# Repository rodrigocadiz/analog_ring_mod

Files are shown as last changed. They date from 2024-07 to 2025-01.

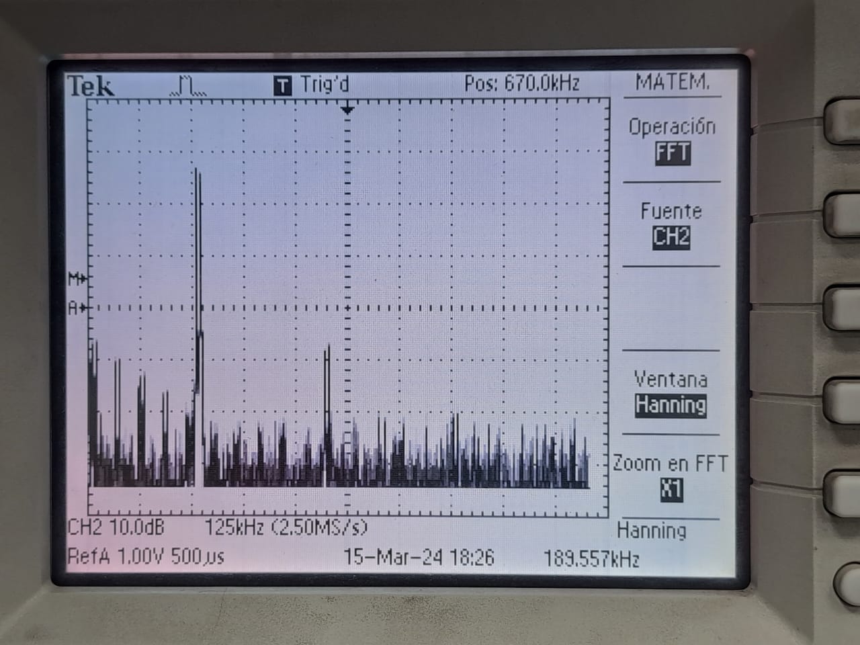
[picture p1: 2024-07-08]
LTSpice paper simulations/Simulaciones paper/Imágenes simulaciones reales/AD633.jpeg

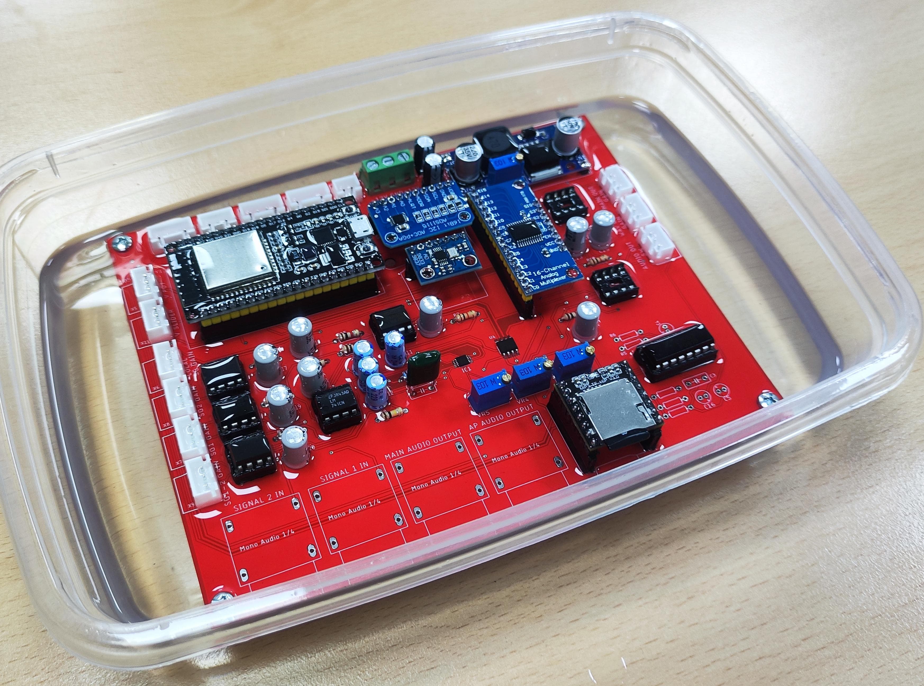
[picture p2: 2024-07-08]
LTSpice paper simulations/Simulaciones paper/Imágenes simulaciones reales/PCB.jpeg

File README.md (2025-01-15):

# Analog ring modulation: a DIY approach inspired by historical techniques

## Overview

We present a device that implements a ring modulator intended to recreate historical analog audio. As simple as it sounds, the multiplication of two analog audio signals is not a straightforward task, mainly due to phenomena such as saturation or non-linearity. Drawing inspiration from historical realizations of ring modulation, we experimented with the most common methods described in the literature. Our device, which is comparatively inexpensive, improves upon the aforementioned alternatives from a DIY perspective. It is predominantly analog, adhering to the practices of the first decades of electroacoustic music, with the notable exception of the digital control for the sinusoidal carrier. We aim to strike a balance between analog audio technology and modern components and techniques. Additionally, this paper includes audio-visual demonstrations that showcase the practical uses of our ring modulator. A comprehensive GitHub repository provides open access to all the resources required for DIY enthusiasts to replicate our implementation.

## Authors
Tomas Koljatic, Michel Rozas, Cristián Garcés, Juan Parra Cancino, Rodrigo F. Cádiz

Pontificia Universidad Católica de Chile

Orpheus Instituut

## Demo videos 
Video 1:
IMAGE ALT TEXT (http://www.youtube.com/watch?v=Msjlwba8t8I "Analog ring modulation: a DIY approach inspired by historical techniques: Video 1")

Video 2: 
IMAGE ALT TEXT (http://www.youtube.com/watch?v=kj30MS5Sc_M "Analog ring modulation: a DIY approach inspired by historical techniques: Video 2")

## Software Installation

The software for the Ring Modulator project is developed to be used with PlatformIO, an open source ecosystem for IoT development. To get started with PlatformIO, you can follow the installation guide here:

- [PlatformIO Installation Guide](https://docs.platformio.org/en/latest/core/installation.html)

Once PlatformIO is installed, you can clone this repository and open the firmware folder project within PlatformIO IDE.

## Hardware Design

The hardware for the Ring Modulator is developed using Autodesk Eagle. This provides a robust framework for designing printed circuit boards (PCBs) that are crucial for our project. You can find the hardware design files in the `hardware` directory of this repository.

For those new to Autodesk Eagle, you can learn more and get started with your designs here:

- [Autodesk Eagle](https://www.autodesk.com/products/eagle/overview)

## Acknowledgments/Contributing

The authors would like to thank Stockahusen Stiftung fur Musik for their support; María Julia Mancero for her participation as a piano performer in the videos; and the anonymous reviewers for their insightful comments and suggestions. This project was funded by the Office for the Arts and Culture of the Vice Presidency for Research, Pontificia Universidad Católica de Chile (ArTeCiH grant) and by ANID/Fondecyt 1230926 and ANID/Anillo ATE220041.

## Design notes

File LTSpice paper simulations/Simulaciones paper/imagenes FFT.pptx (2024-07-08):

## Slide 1

Time and frequency domain response for diode and opamps based modulator

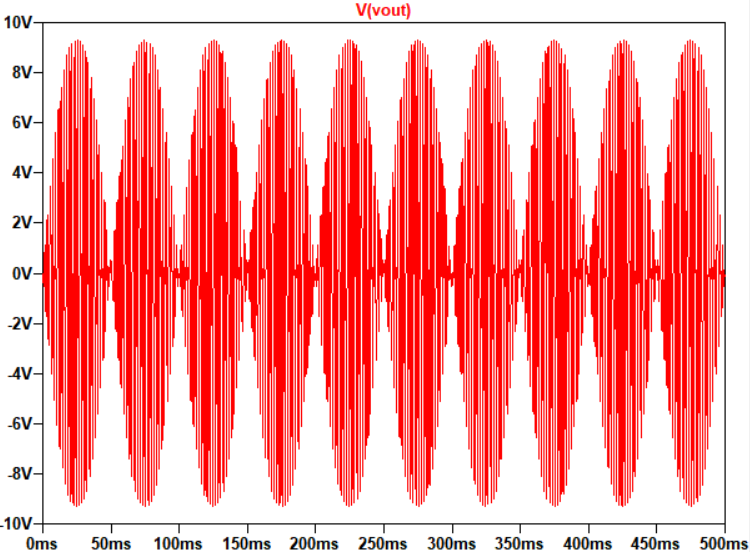
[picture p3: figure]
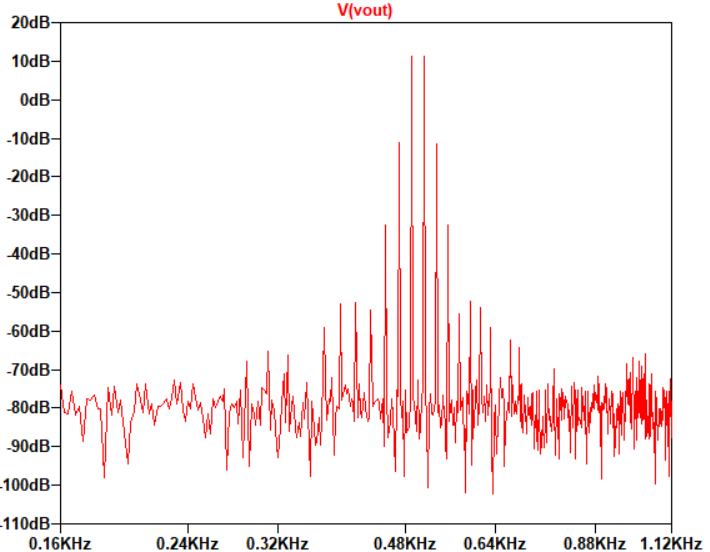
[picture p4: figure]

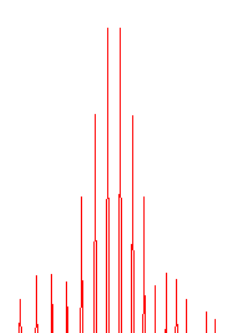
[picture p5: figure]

useful frequencies

20dB

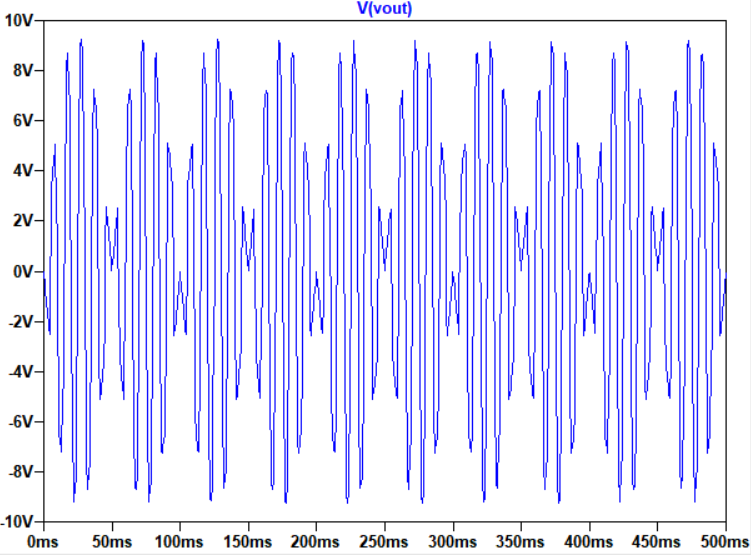
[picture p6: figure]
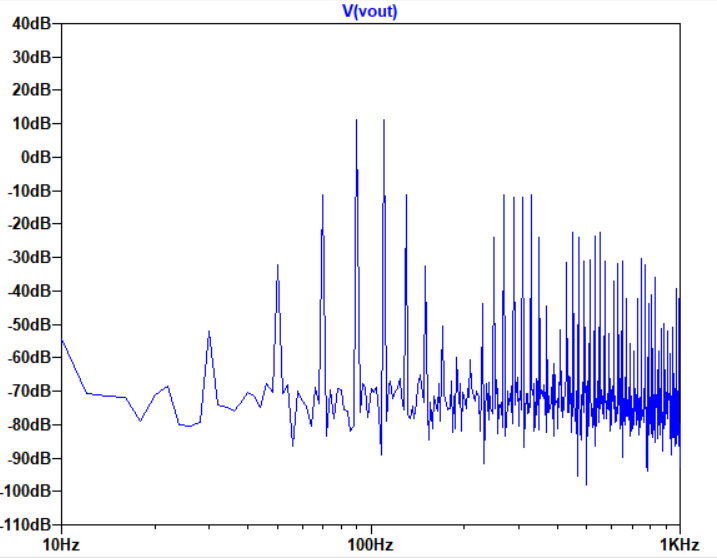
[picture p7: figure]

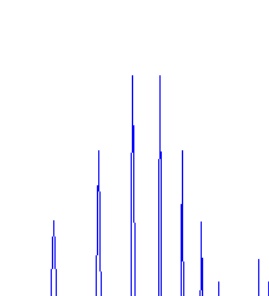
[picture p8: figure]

useful frequencies

20dB

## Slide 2

Time and frequency domain response for MOSFET and opamps based modulator

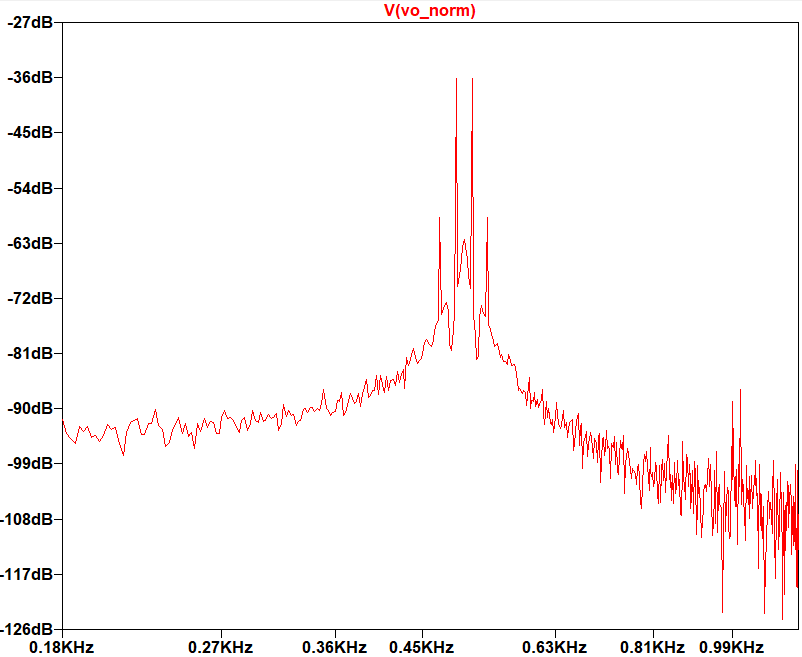
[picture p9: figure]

useful frequencies

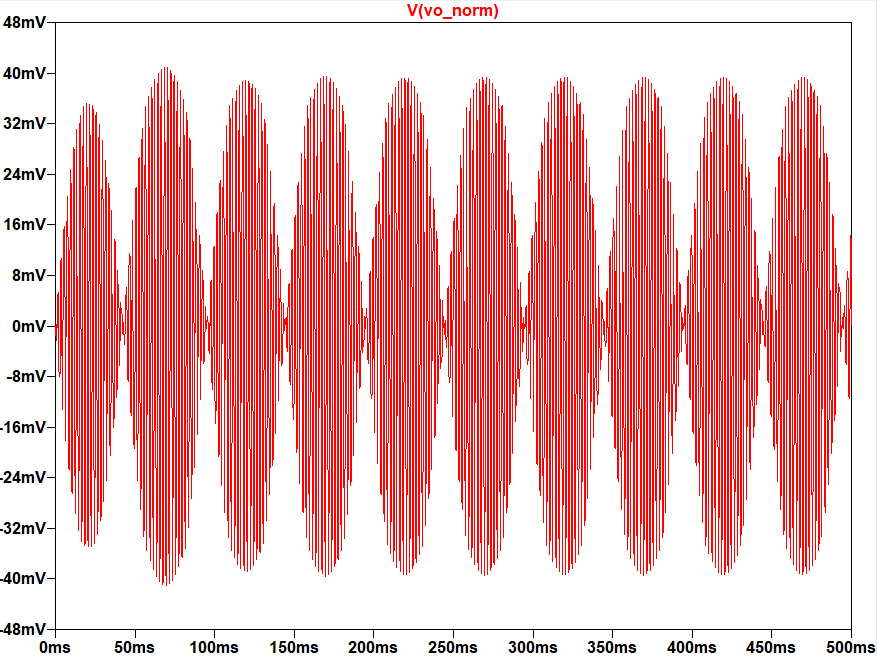
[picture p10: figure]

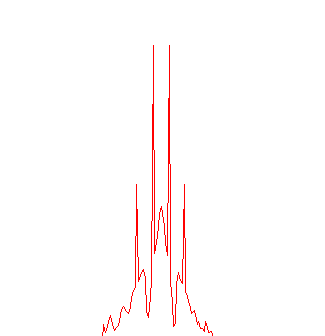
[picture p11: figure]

36 dB

useful frequencies

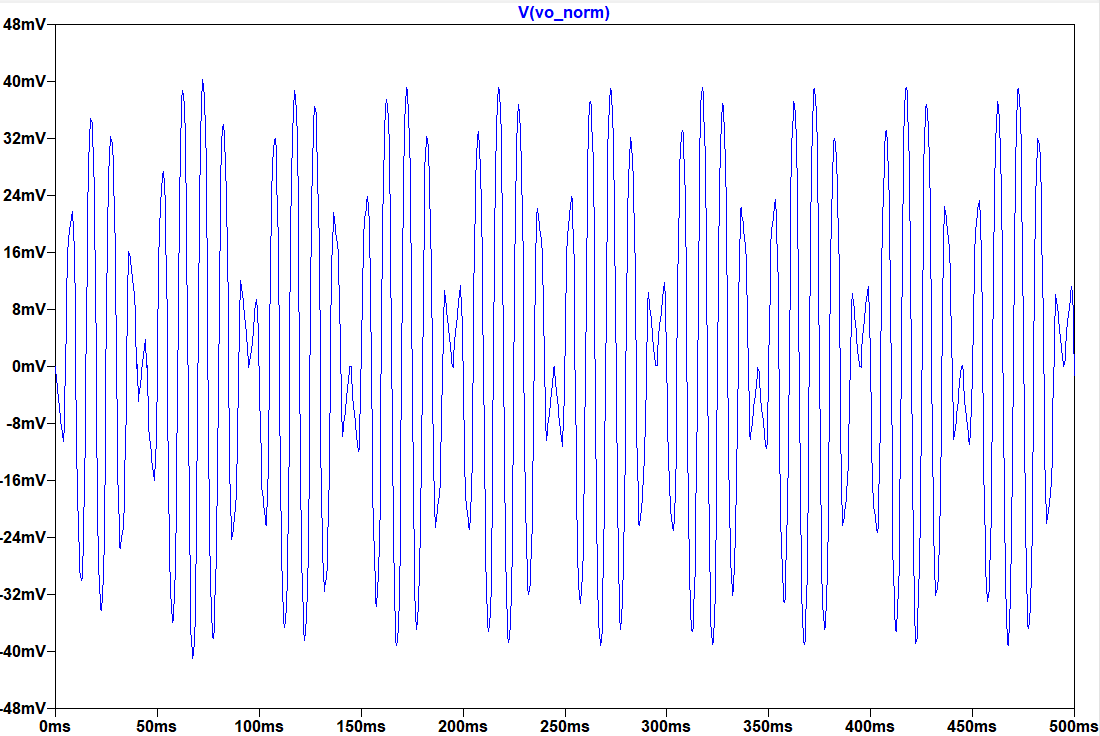
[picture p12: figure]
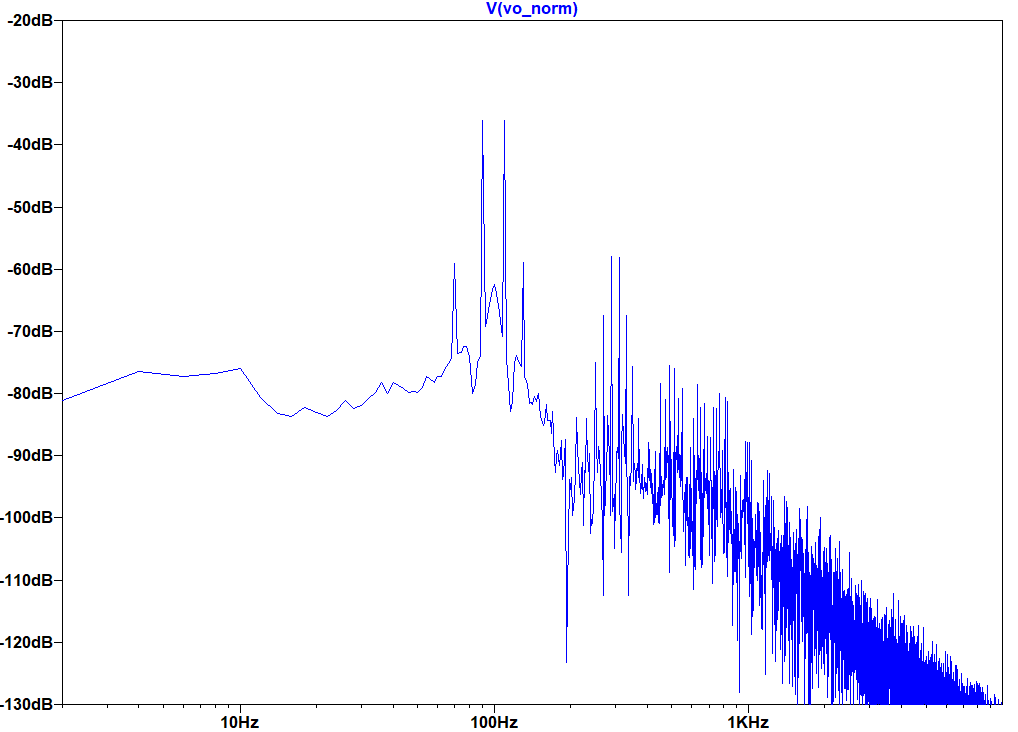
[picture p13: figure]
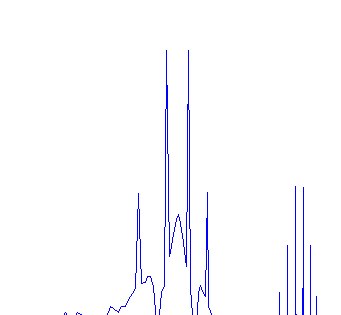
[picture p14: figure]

40dB

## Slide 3

Time and frequency domain response for AD633 IC based modulator

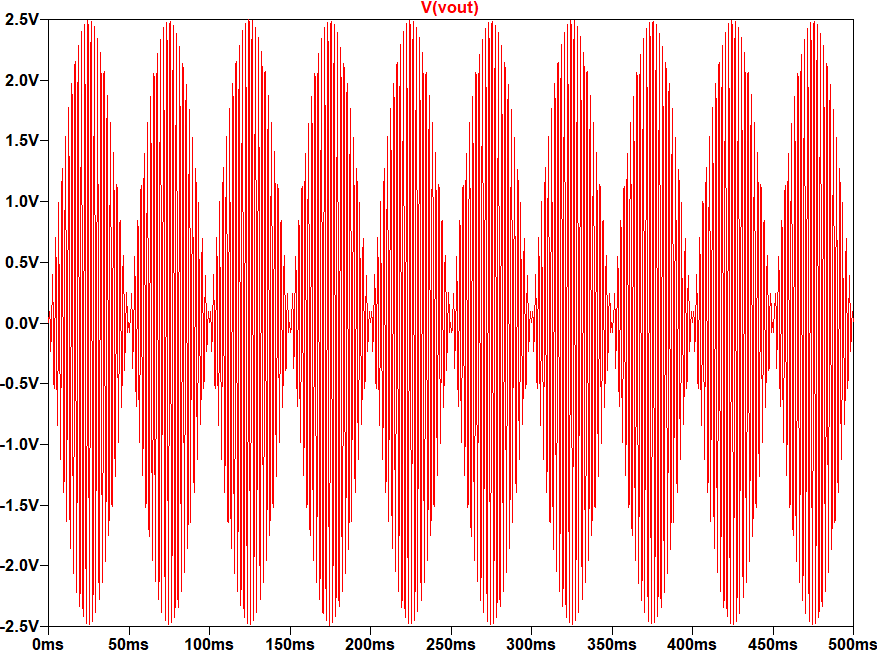
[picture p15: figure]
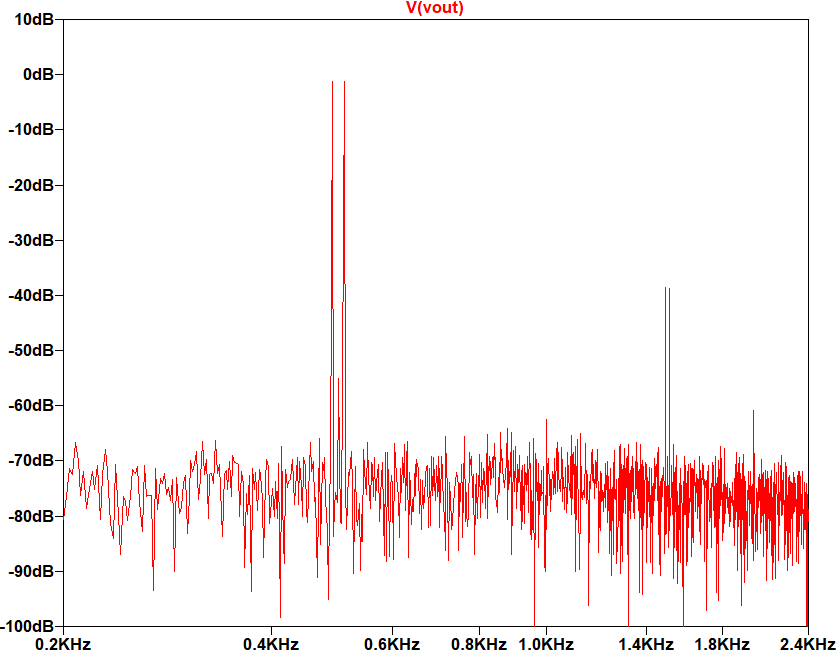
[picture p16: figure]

useful frequencies

40 dB

useful frequencies

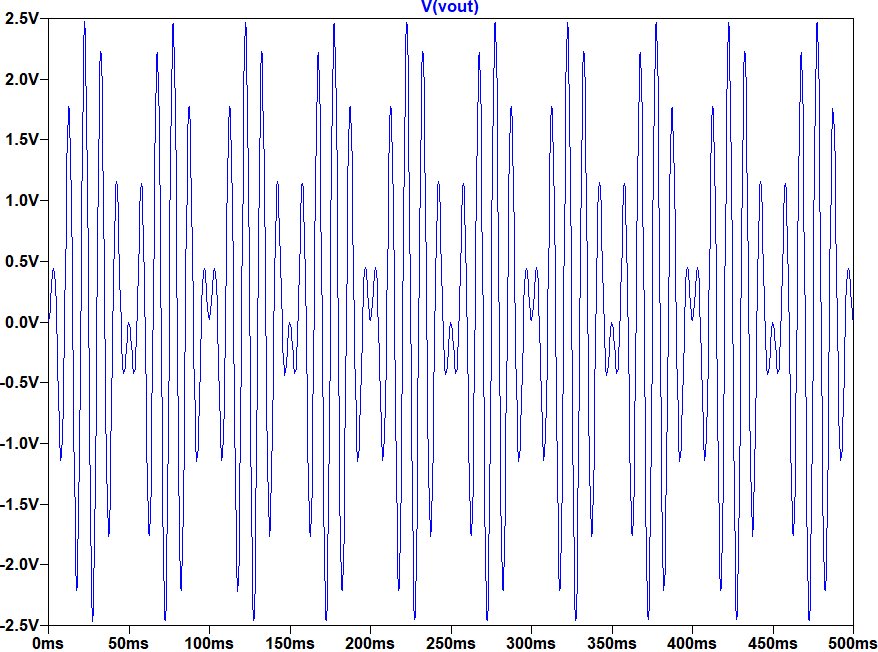
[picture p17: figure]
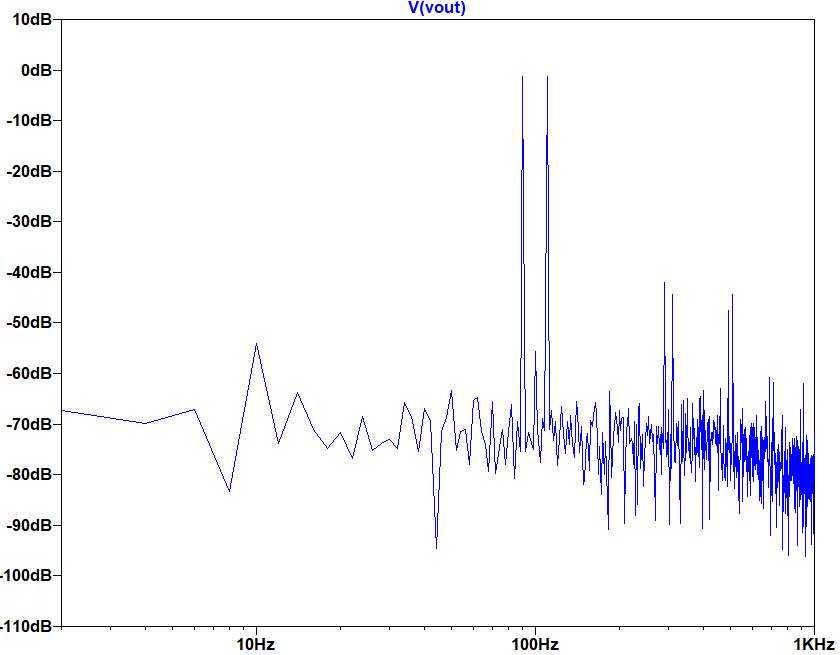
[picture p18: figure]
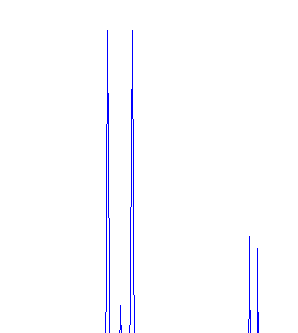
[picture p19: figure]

50dB

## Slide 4

Time and frequency domain response for transformer and diodes based modulator

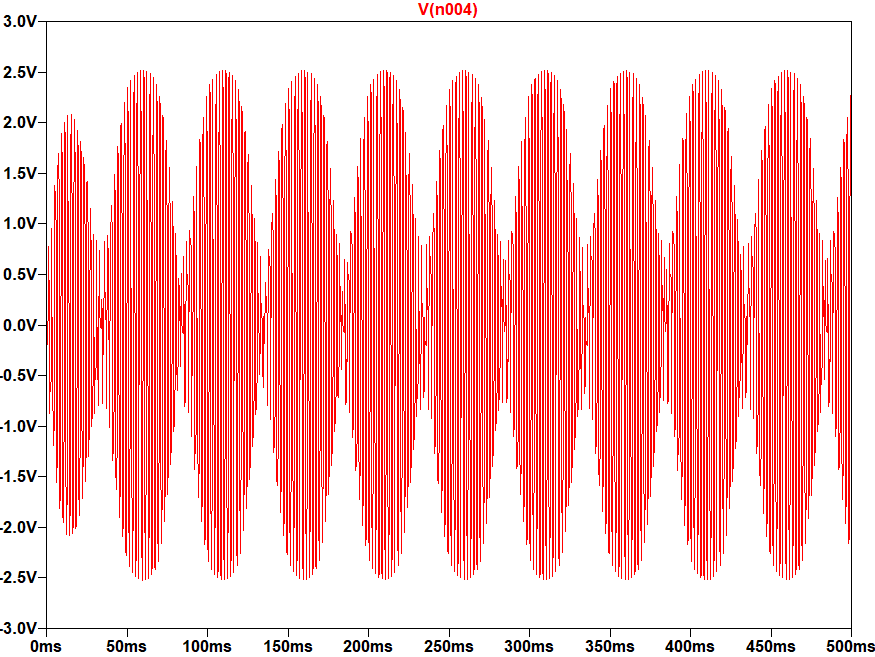
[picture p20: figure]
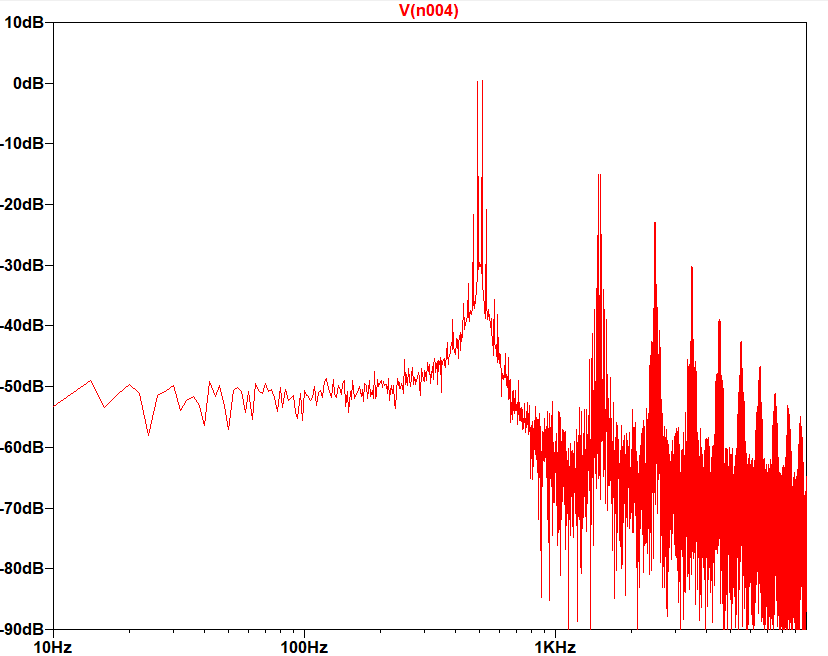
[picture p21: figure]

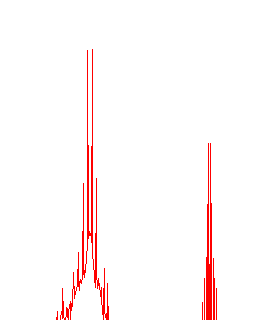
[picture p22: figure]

useful frequencies

20dB

useful frequencies

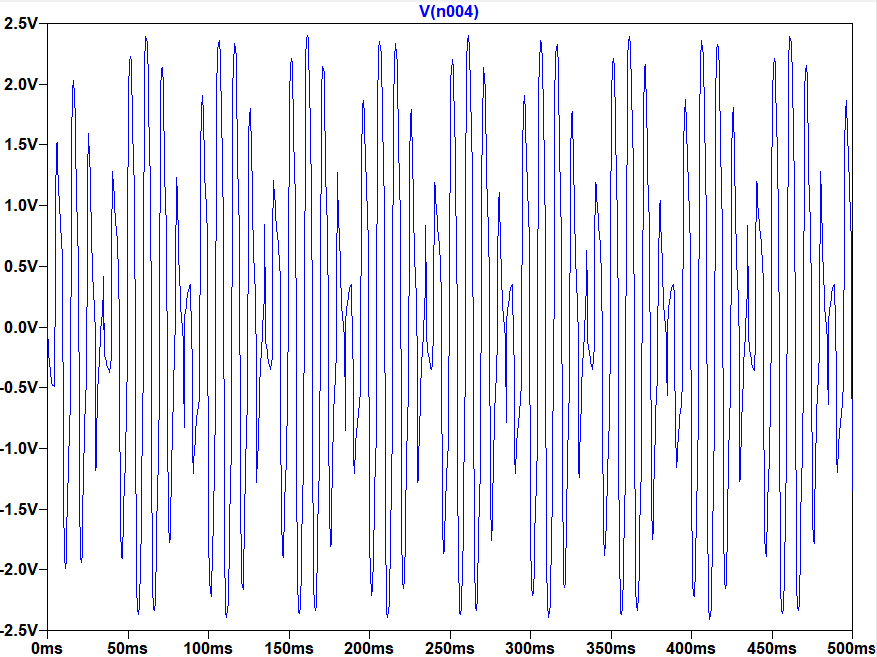
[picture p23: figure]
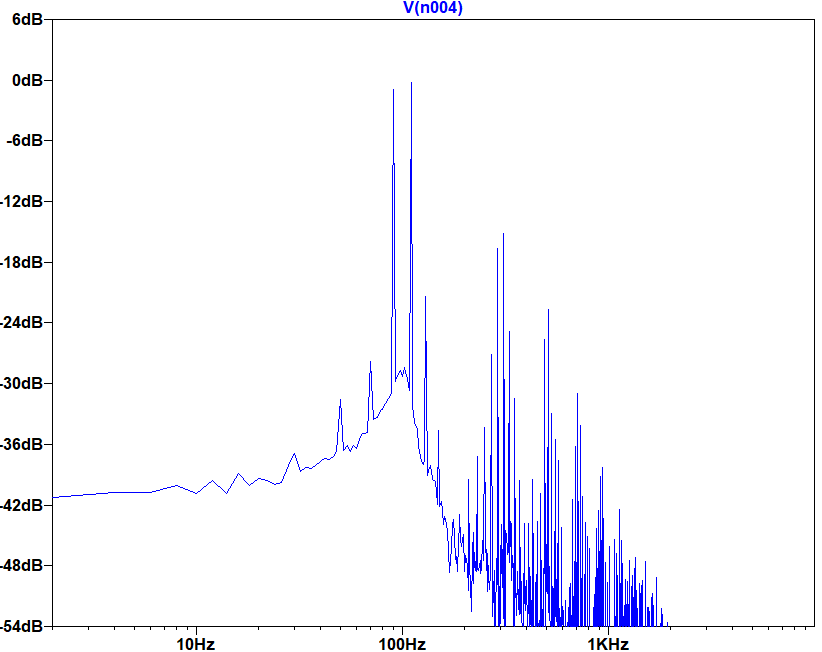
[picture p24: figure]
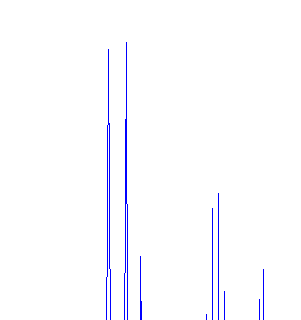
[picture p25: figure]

15 dB

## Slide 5

Time and frequency domain response for transformer and diodes based modulator

useful frequencies

20dB

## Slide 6

Time and frequency domain response for diode and op-amps based modulator

useful frequencies

20dB

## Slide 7

Time and frequency domain response for MOSFET and op-amps based modulator

useful frequencies

36 dB

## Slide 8

Time and frequency domain response for AD633 IC based modulator

useful frequencies

40 dB

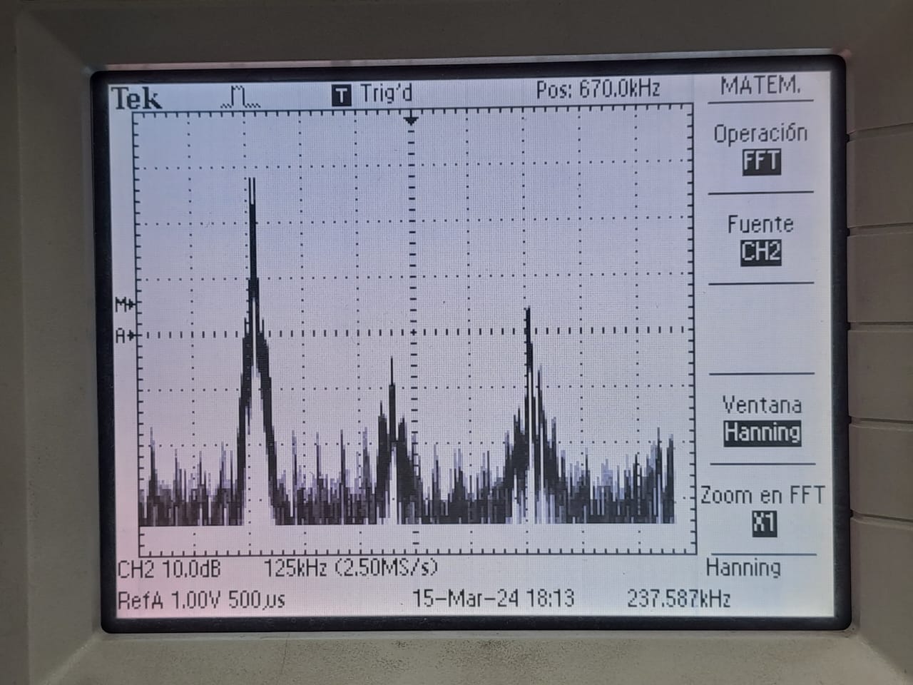
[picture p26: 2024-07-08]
LTSpice paper simulations/Simulaciones paper/Imágenes simulaciones reales/Diodos y opamps.jpeg

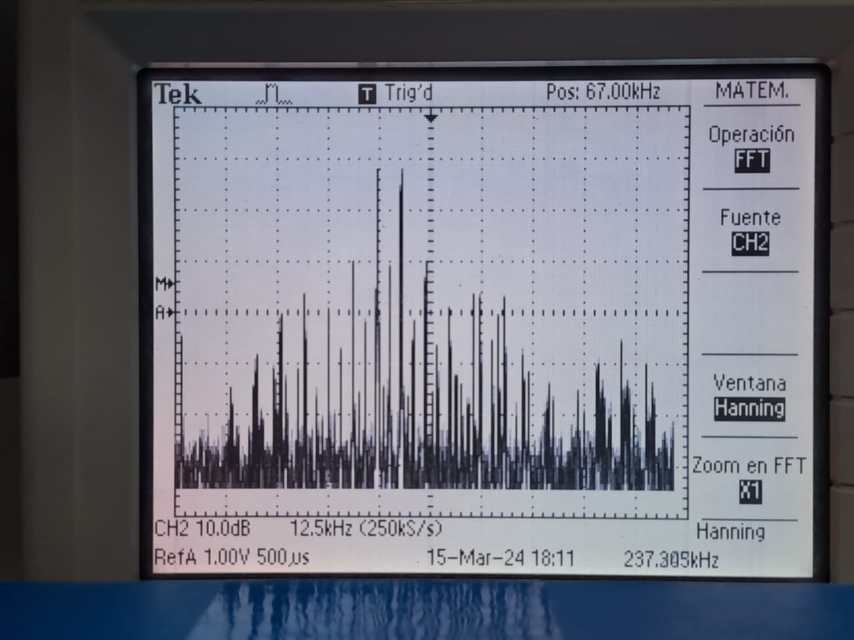
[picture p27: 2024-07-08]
LTSpice paper simulations/Simulaciones paper/Imágenes simulaciones reales/Diodos y opamps (zoom).jpeg

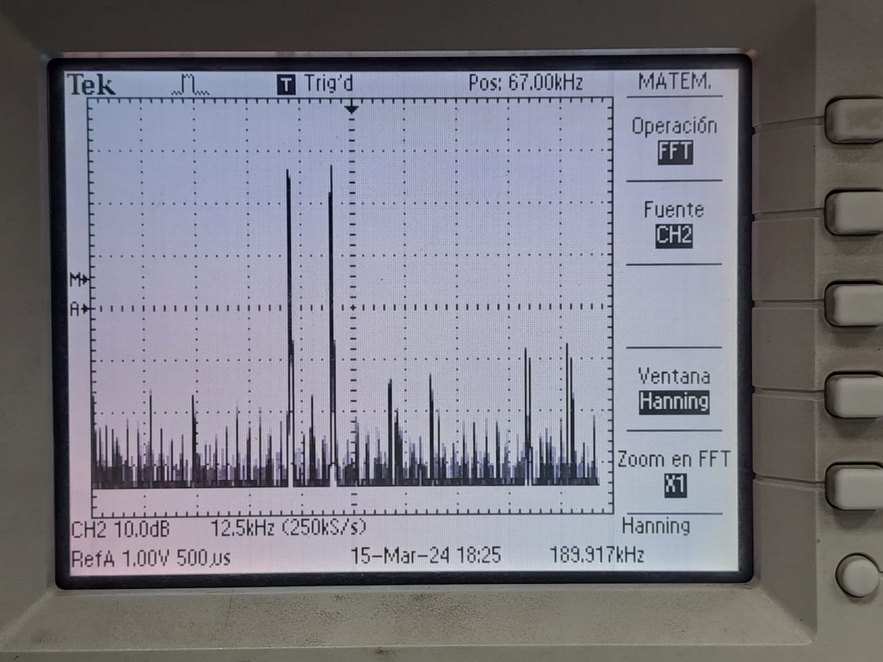
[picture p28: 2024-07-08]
LTSpice paper simulations/Simulaciones paper/Imágenes simulaciones reales/AD633 (zoom).jpeg

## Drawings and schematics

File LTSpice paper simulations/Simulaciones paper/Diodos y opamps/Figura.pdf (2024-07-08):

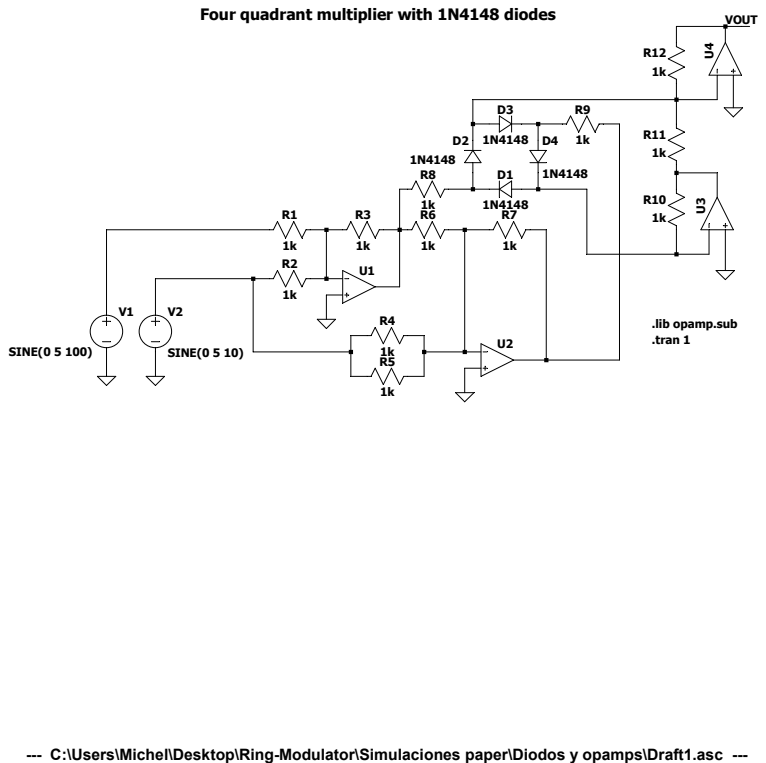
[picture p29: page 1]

Four quadrant multiplier with 1N4148 diodes

--- C:\Users\Michel\Desktop\Ring-Modulator\Simulaciones paper\Diodos y opamps\Draft1.asc ---

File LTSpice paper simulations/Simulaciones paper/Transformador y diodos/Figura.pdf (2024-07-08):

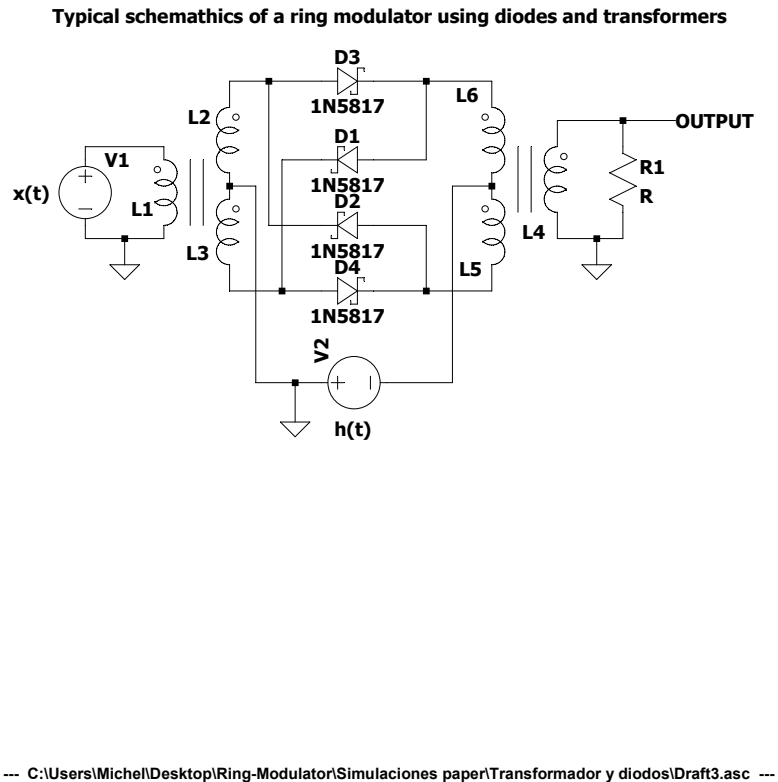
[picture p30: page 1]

Typical schemathics of a ring modulator using diodes and transformers

--- C:\Users\Michel\Desktop\Ring-Modulator\Simulaciones paper\Transformador y diodos\Draft3.asc ---

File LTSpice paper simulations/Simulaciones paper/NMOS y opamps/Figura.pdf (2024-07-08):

## Four quadrant multiplier using NMOS and opamps

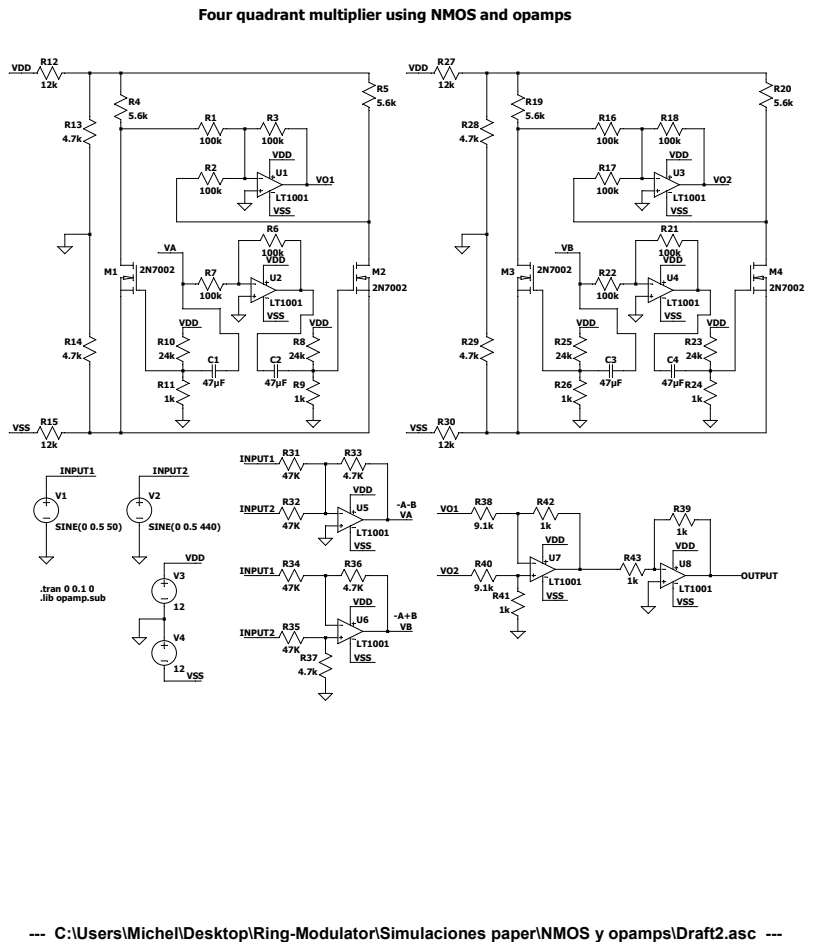
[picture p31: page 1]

--- C:\Users\Michel\Desktop\Ring-Modulator\Simulaciones paper\NMOS y opamps\Draft2.asc ---

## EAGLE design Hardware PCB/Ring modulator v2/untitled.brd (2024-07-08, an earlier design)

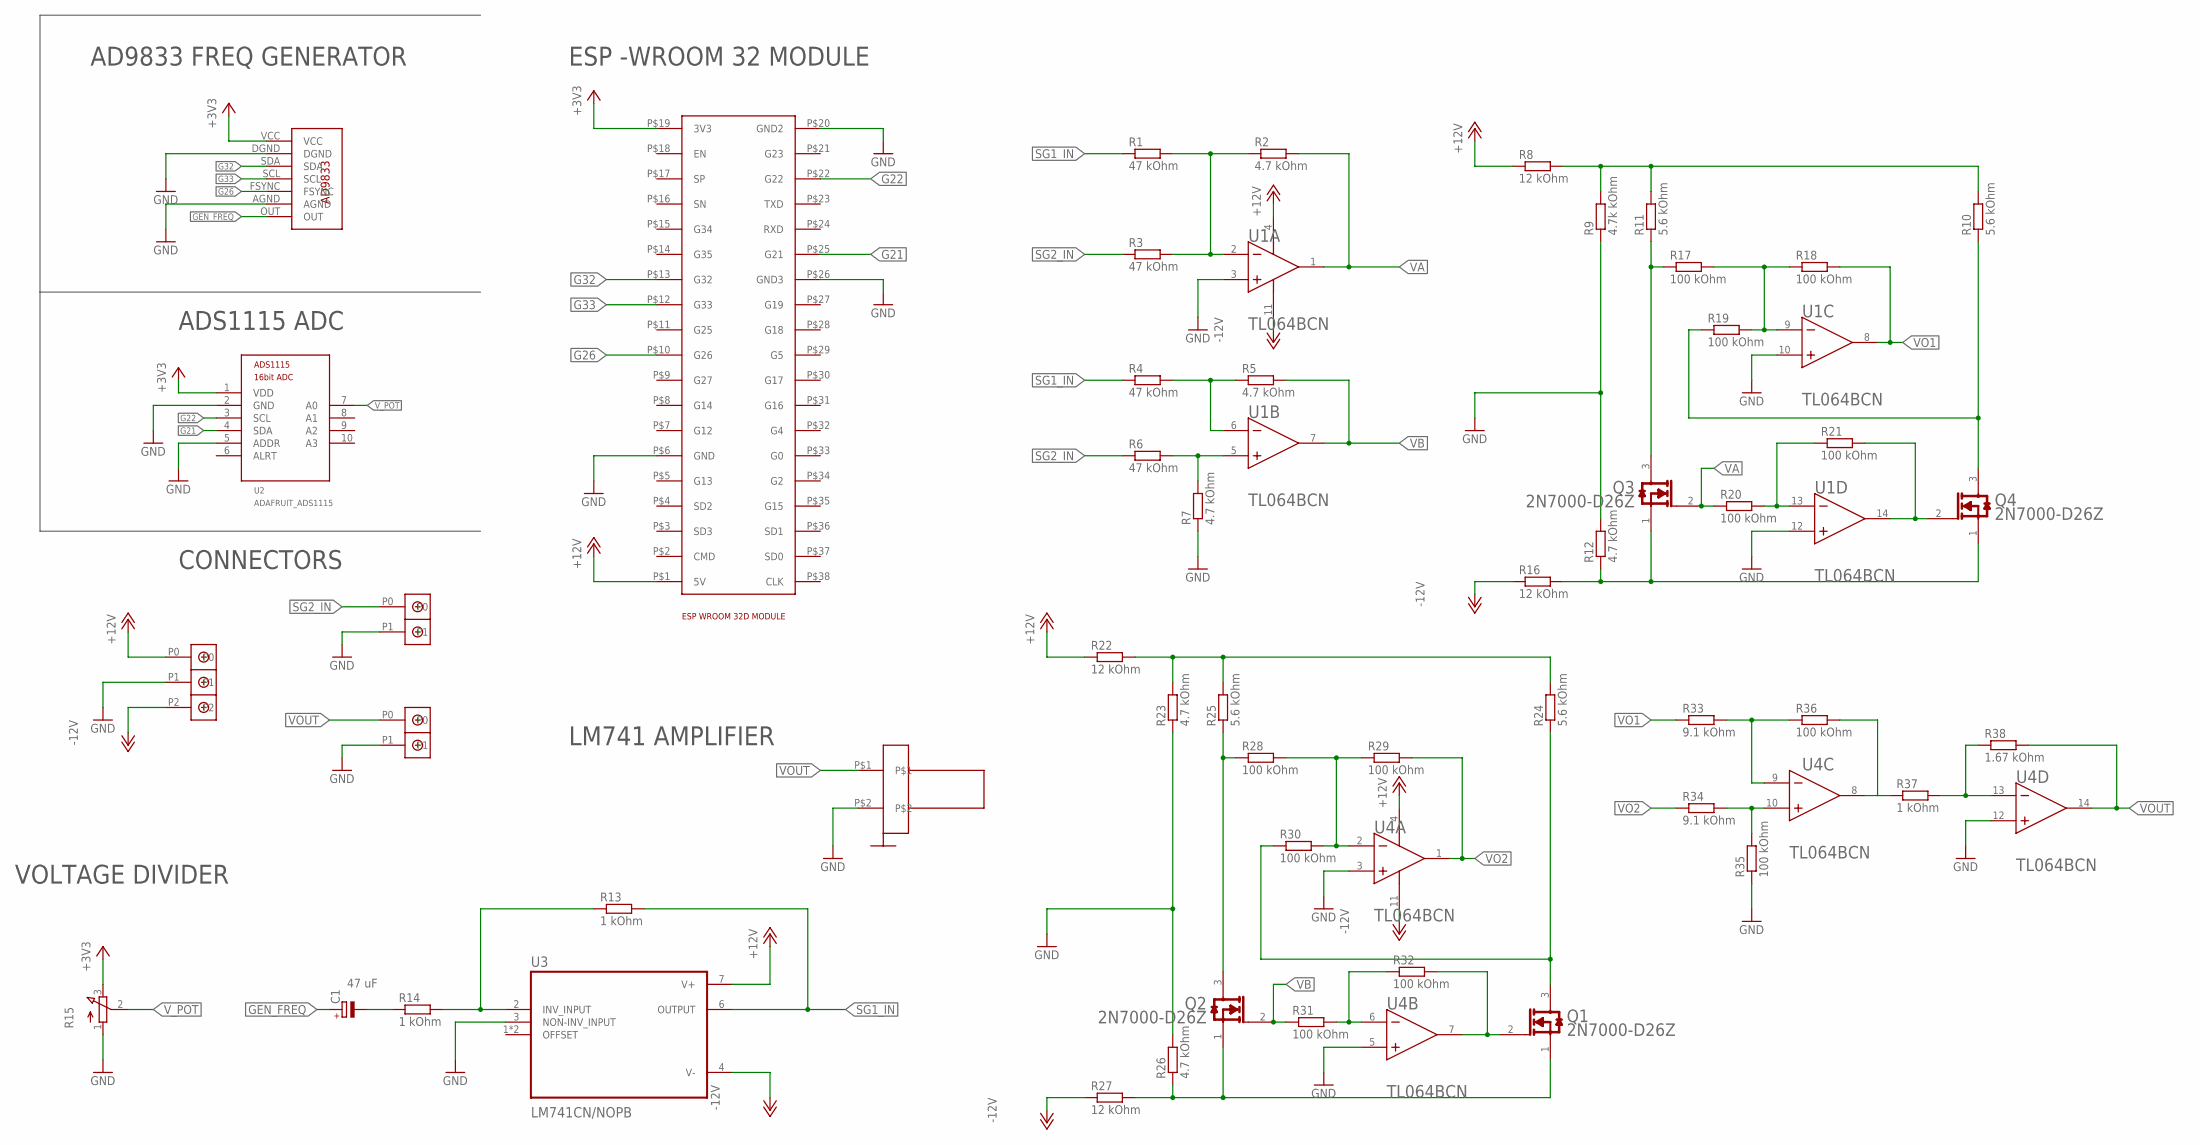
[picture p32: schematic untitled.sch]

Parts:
C1: 47 uF; E1,8-4
Q1, Q2, Q3, Q4: ON_SEMICONDUCTOR_2N7000-D26ZON_SEMICONDUCTOR_2N70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; ON_SEMICONDUCTOR_2N7000-D26Z_0
R1, R3, R4, R6: 47 kOhm; 0204/7
R2, R5, R7, R12, R23, R26: 4.7 kOhm; 0204/7
R8, R16, R22, R27: 12 kOhm; 0204/7
R9: 4.7k kOhm; 0204/7
R10, R11, R24, R25: 5.6 kOhm; 0204/7
R13, R14, R37: 1 kOhm; 0204/7
R15: 3RP/1610N
R17, R18, R19, R20, R21, R28, R29, R30, R31, R32, R35, R36: 100 kOhm; 0204/7
R33, R34: 9.1 kOhm; 0204/7
R38: 1.67 kOhm; 0204/7
U1, U4: TEXAS_INSTRUMENTS_TL064BCNTEXAS_INSTRUMENTS_TL064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; TEXAS_INSTRUMENTS_TL064BCN_0
U2: ADAFRUIT_ADS1115; ADAFRUIT_ADS1115_16BIT_I2C_ADC
U3: LM741CN/NOPB; DIP794W45P254L959H508Q8
U$1: ESP32
U$2: A9833; AD9833
U$3, U$5: DBCONN-1X2
U$4: DBCONN-1X3
U$6: FP

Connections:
+3V3: R15.3 (E), U2.1 (VDD), U$1.P$19 (3V3), U$2.VCC
+12V: R8.1, R22.1, U1.4 (VCC+), U3.7 (V+), U4.4 (VCC+), U$1.P$1 (5V), U$4.P0
-12V: R16.1, R27.1, U1.11 (VCC-), U3.4 (V-), U4.11 (VCC-), U$4.P2
G21: U2.4 (SDA), U$1.P$25 (G21)
G22: U2.3 (SCL), U$1.P$22 (G22)
G26: U$1.P$10 (G26), U$2.FSYNC
G32: U$1.P$13 (G32), U$2.SDA
G33: U$1.P$12 (G33), U$2.SCL
GEN_FREQ: C1.+, U$2.OUT
GND: R7.1, R9.1, R12.2, R15.1 (A), R23.1, R26.2, R35.1, U1.3 (IN1+), U1.10 (IN3+), U1.12 (IN4+), U2.2 (GND), U2.5 (ADDR), U3.3 (NON-INV_INPUT), U4.3 (IN1+), U4.5 (IN2+), U4.12 (IN4+), U$1.P$6 (GND), U$1.P$20 (GND2), U$1.P$26 (GND3), U$2.AGND, U$2.DGND, U$3.P1, U$4.P1, U$5.P1, U$6.P$2
unnamed: R1.2, R2.1, R3.2, U1.2 (IN1-)
unnamed: R4.2, R5.1, U1.6 (IN2-)
unnamed: R8.2, R9.2, R10.2, R11.2
unnamed: R13.1, R14.2, U3.2 (INV_INPUT)
unnamed: C1.-, R14.1
unnamed: R6.2, R7.2, U1.5 (IN2+)
unnamed: Q3.3 (D), R11.1, R17.1
unnamed: Q3.1 (S), Q4.1 (S), R12.1, R16.2
unnamed: Q4.3 (D), R10.1, R19.1
unnamed: R37.2, R38.1, U4.13 (IN4-)
unnamed: R20.2, R21.1, U1.13 (IN4-)
unnamed: R17.2, R18.1, R19.2, U1.9 (IN3-)
unnamed: Q4.2 (G), R21.2, U1.14 (OUT4)
unnamed: R22.2, R23.2, R24.2, R25.2
unnamed: Q1.1 (S), Q2.1 (S), R26.1, R27.2
unnamed: Q2.3 (D), R25.1, R28.1
unnamed: Q1.3 (D), R24.1, R30.1
unnamed: R28.2, R29.1, R30.2, U4.2 (IN1-)
unnamed: R33.2, R36.1, U4.9 (IN3-)
unnamed: R31.2, R32.1, U4.6 (IN2-)
unnamed: Q1.2 (G), R32.2, U4.7 (OUT2)
unnamed: R36.2, R37.1, U4.8 (OUT3)
unnamed: R34.2, R35.2, U4.10 (IN3+)
SG1_IN: R1.1, R4.1, R13.2, U3.6 (OUTPUT)
SG2_IN: R3.1, R6.1, U$3.P0
VA: Q3.2 (G), R2.2, R20.1, U1.1 (OUT1)
VB: Q2.2 (G), R5.2, R31.1, U1.7 (OUT2)
VO1: R18.2, R33.1, U1.8 (OUT3)
VO2: R29.2, R34.1, U4.1 (OUT1)
VOUT: R38.2, U4.14 (OUT4), U$5.P0, U$6.P$1
V_POT: R15.2 (S), U2.7 (A0)

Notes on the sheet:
ESP -WROOM 32 MODULE
AD9833 FREQ GENERATOR
ADS1115 ADC
CONNECTORS
LM741 AMPLIFIER
VOLTAGE DIVIDER

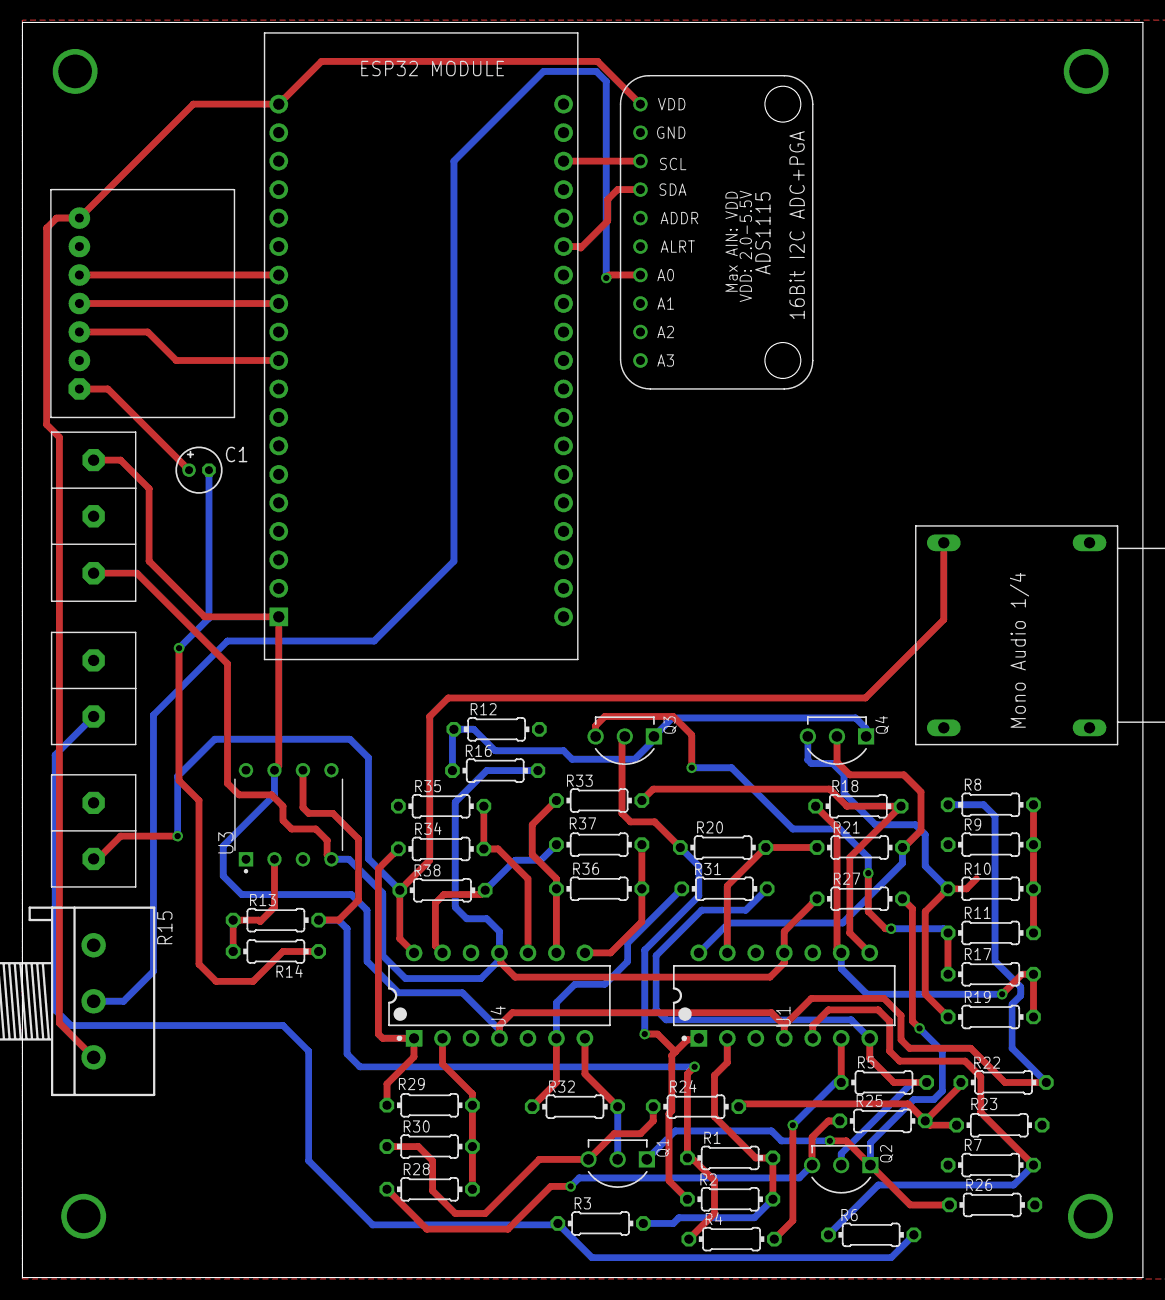
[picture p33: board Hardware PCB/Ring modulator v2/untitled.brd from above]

Board: 2 copper layers, 99.9 x 111.9 mm, 53 parts (0 on the bottom side), 41 nets.

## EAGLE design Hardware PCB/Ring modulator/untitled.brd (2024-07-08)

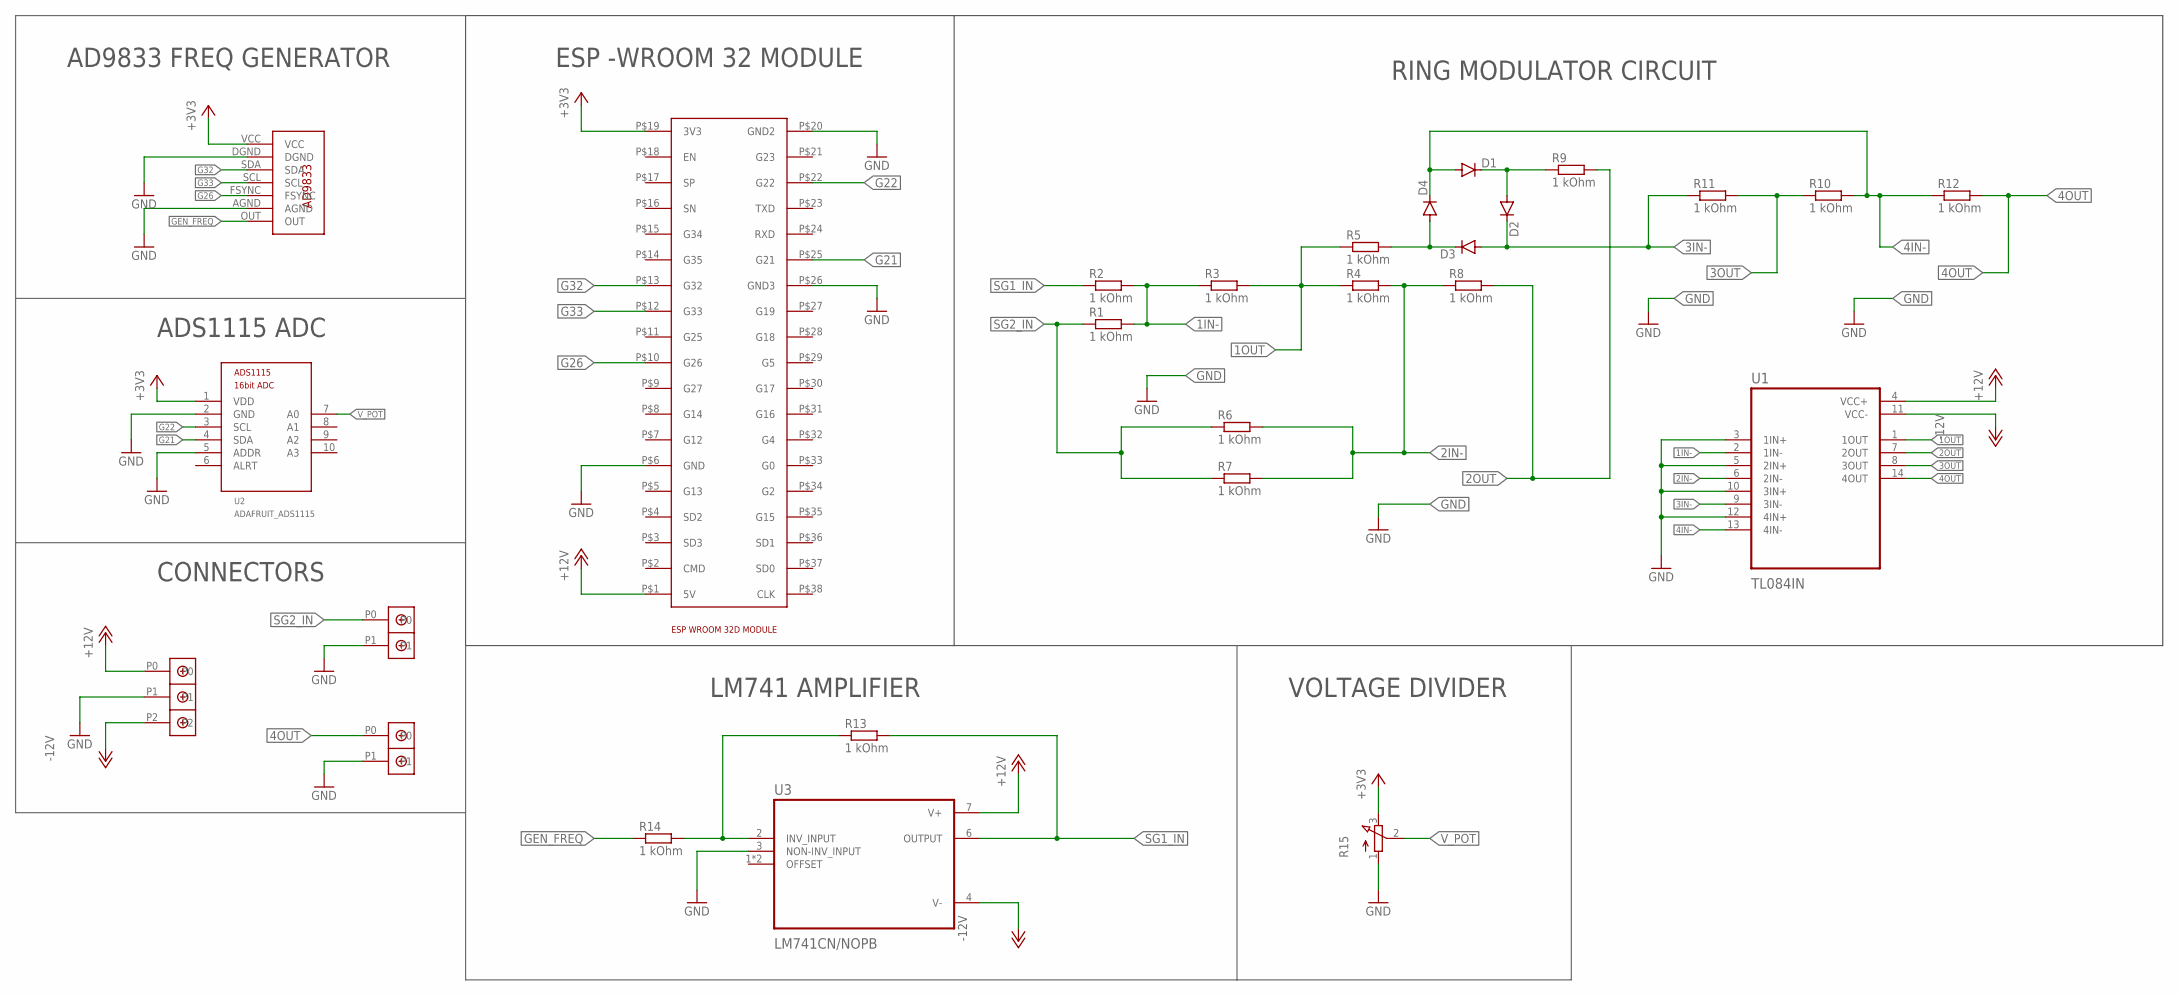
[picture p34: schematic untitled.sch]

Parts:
D1, D2, D3, D4: 1N4148DO35-7; DO35-7
R1, R2, R3, R4, R5, R6, R7, R8, R9, R10, R11, R12, R13, R14: 1 kOhm; 0204/7
R15: 3RP/1610N
U1: TL084IN; DIP794W45P254L1969H508Q14
U2: ADAFRUIT_ADS1115; ADAFRUIT_ADS1115_16BIT_I2C_ADC
U3: LM741CN/NOPB; DIP794W45P254L959H508Q8
U$1: ESP32
U$2: A9833; AD9833
U$3, U$5: DBCONN-1X2
U$4: DBCONN-1X3

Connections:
1IN-: R1.2, R2.2, R3.1, U1.2 (1IN-)
1OUT: R3.2, R4.1, R5.1, U1.1 (1OUT)
2IN-: R4.2, R6.2, R7.2, R8.1, U1.6 (2IN-)
2OUT: R8.2, R9.2, U1.7 (2OUT)
3IN-: D2.C, D3.A, R11.1, U1.9 (3IN-)
3OUT: R10.1, R11.2, U1.8 (3OUT)
4IN-: D1.A, D4.C, R10.2, R12.1, U1.13 (4IN-)
4OUT: R12.2, U1.14 (4OUT), U$5.P0
+3V3: R15.3 (E), U2.1 (VDD), U$1.P$19 (3V3), U$2.VCC
+12V: U1.4 (VCC+), U3.7 (V+), U$1.P$1 (5V), U$4.P0
-12V: U1.11 (VCC-), U3.4 (V-), U$4.P2
G21: U2.4 (SDA), U$1.P$25 (G21)
G22: U2.3 (SCL), U$1.P$22 (G22)
G26: U$1.P$10 (G26), U$2.FSYNC
G32: U$1.P$13 (G32), U$2.SDA
G33: U$1.P$12 (G33), U$2.SCL
GEN_FREQ: R14.1, U$2.OUT
GND: R15.1 (A), U1.3 (1IN+), U1.5 (2IN+), U1.10 (3IN+), U1.12 (4IN+), U2.2 (GND), U2.5 (ADDR), U3.3 (NON-INV_INPUT), U$1.P$6 (GND), U$1.P$20 (GND2), U$1.P$26 (GND3), U$2.AGND, U$2.DGND, U$3.P1, U$4.P1, U$5.P1
unnamed: D3.C, D4.A, R5.2
unnamed: D1.C, D2.A, R9.1
unnamed: R13.1, R14.2, U3.2 (INV_INPUT)
SG1_IN: R2.1, R13.2, U3.6 (OUTPUT)
SG2_IN: R1.1, R6.1, R7.1, U$3.P0
V_POT: R15.2 (S), U2.7 (A0)

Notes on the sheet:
RING MODULATOR CIRCUIT
ESP -WROOM 32 MODULE
AD9833 FREQ GENERATOR
ADS1115 ADC
CONNECTORS
LM741 AMPLIFIER
VOLTAGE DIVIDER

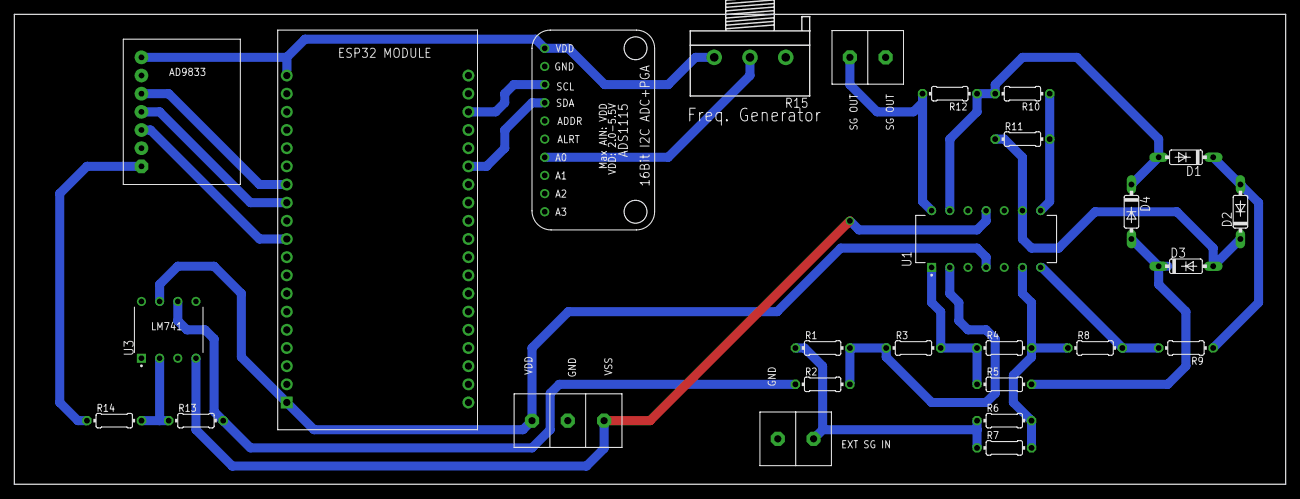
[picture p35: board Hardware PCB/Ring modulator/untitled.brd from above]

Board: 2 copper layers, 177.8 x 65.7 mm, 27 parts (0 on the bottom side), 24 nets.

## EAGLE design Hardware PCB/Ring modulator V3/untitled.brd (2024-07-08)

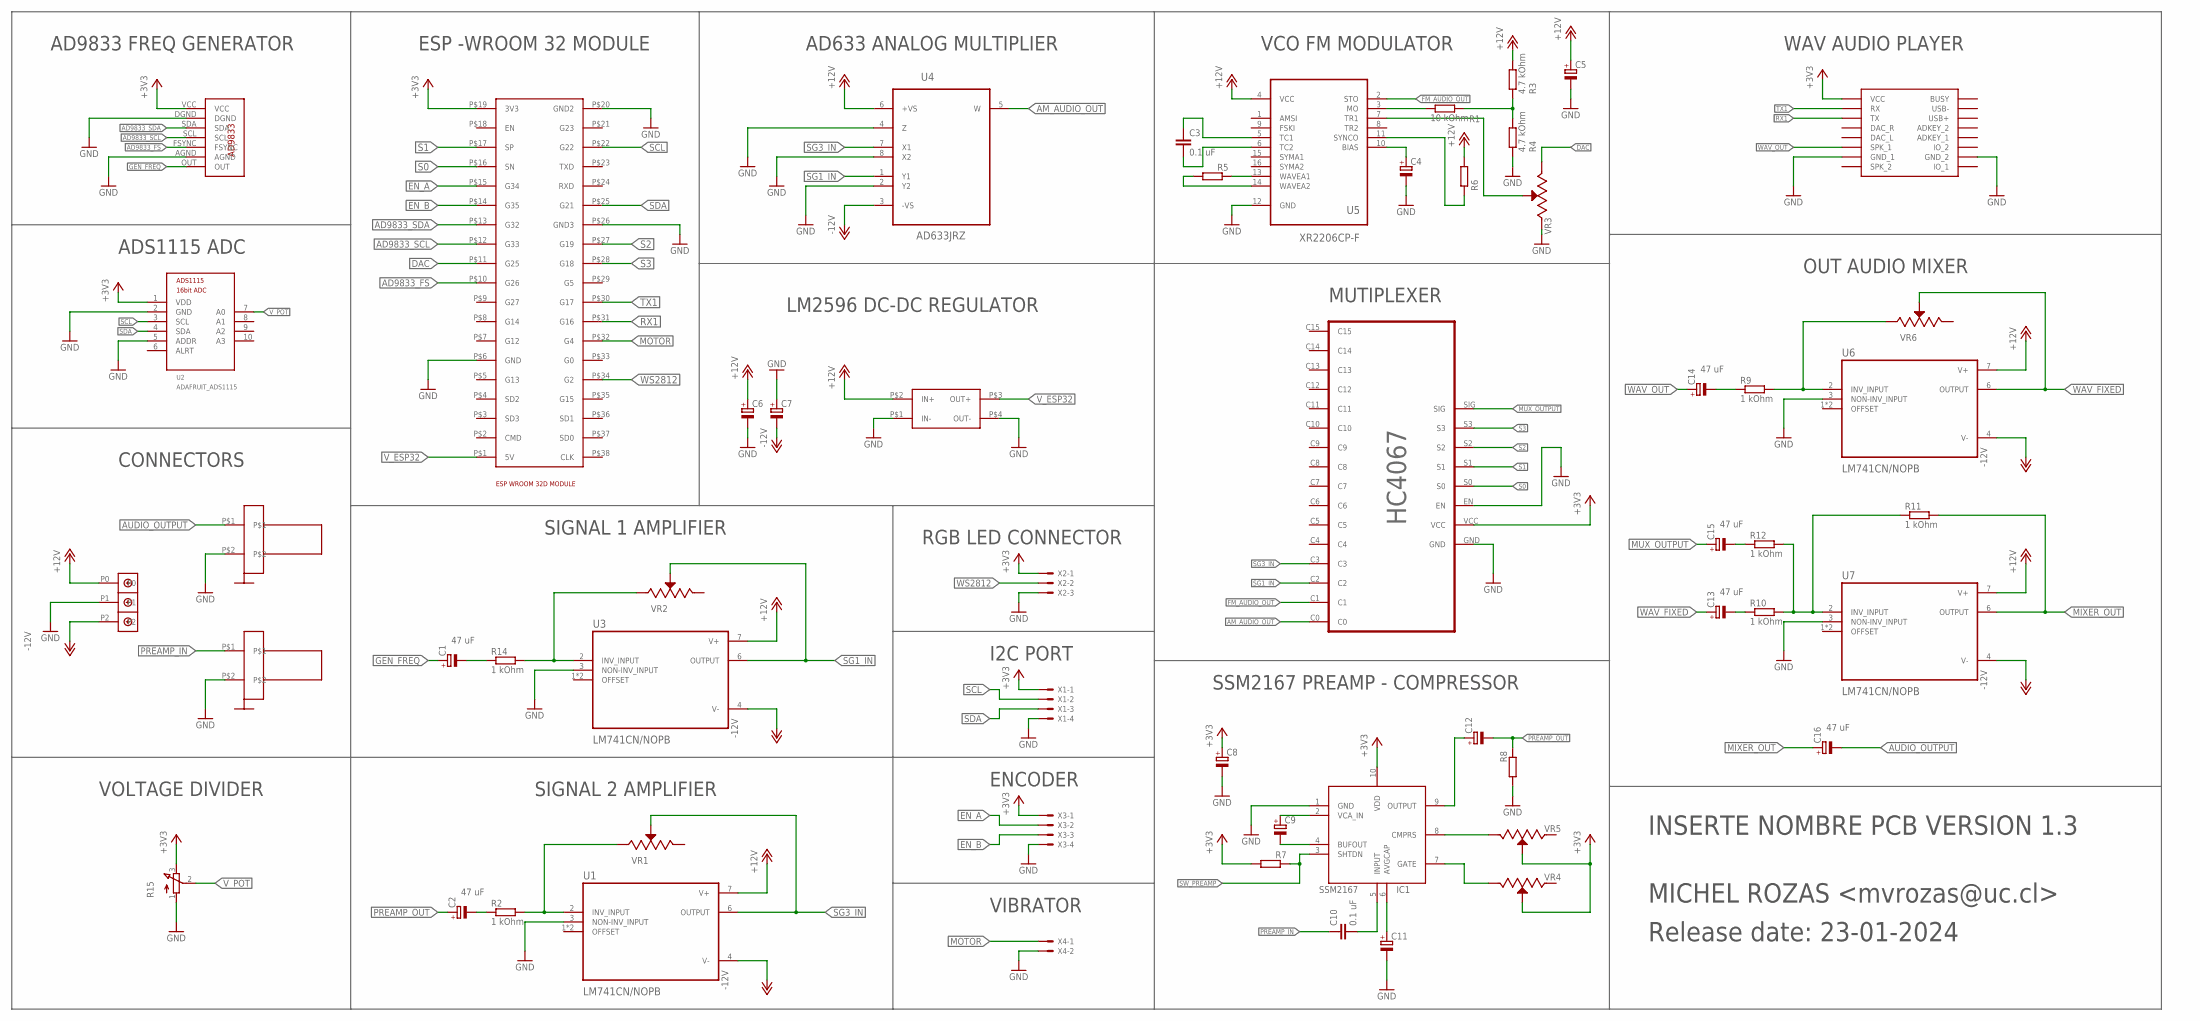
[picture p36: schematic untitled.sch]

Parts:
C1, C2, C13, C14, C15, C16: 47 uF; E1,8-4
C3, C10: 0.1 uF; C050-030X075
C4, C5: 1 uF; E1,8-4
C6, C7: 100 uF; E1,8-4
C8, C9, C11, C12: 10 uF; E1,8-4
IC1: SSM2167; MSOP10
R1, R6: 10 kOhm; 0204/7
R2, R9, R10, R11, R12, R14: 1 kOhm; 0204/7
R3, R4: 4.7 kOhm; 0204/7
R5: 200 Ohm; 0204/7
R7: 500 kOhm; 0204/7
R8: 100 kOhm; 0204/7
R15: 3RP/1610N
U1, U3, U6, U7: LM741CN/NOPB; DIP794W45P254L959H508Q8
U2: ADAFRUIT_ADS1115; ADAFRUIT_ADS1115_16BIT_I2C_ADC
U4: AD633JRZ; SOIC127P600X175-8N
U5: XR2206CP-F; DIP254P762X533-16
U$1: ESP32
U$2: A9833; AD9833
U$3: LM2596
U$4: DBCONN-1X3
U$5: HC4067_BREAKOUT_BOARD; ANALOG_MUX_BREAKOUT_HC4067
U$6, U$7: FP
U$8: DFPLAYER
VR1, VR2, VR3, VR4, VR5, VR6: 3296W-1-104LF; TRIM_3296W-1-104LF
X1, X3: JST-XH-04-PIN-ROUND-PAD; JST-XH-04-PACKAGE-ROUND-PAD
X2: JST-XH-03-PIN-ROUND-PAD; JST-XH-03-PACKAGE-ROUND-PAD
X4: JST-XH-02-PIN-ROUND-PAD; JST-XH-02-PACKAGE-ROUND-PAD

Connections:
+3V3: C8.+, IC1.10 (VDD), R7.1, R15.3 (E), U2.1 (VDD), U$1.P$19 (3V3), U$2.VCC, U$5.VCC, U$8.VCC, VR4.2 (WIPER), VR5.2 (WIPER), X1.1, X2.1, X3.1
+12V: C5.+, C6.+, R3.2, R6.2, U1.7 (V+), U3.7 (V+), U4.6 (+VS), U5.4 (VCC), U6.7 (V+), U7.7 (V+), U$3.P$2 (IN+), U$4.P0
-12V: C7.-, U1.4 (V-), U3.4 (V-), U4.3 (-VS), U6.4 (V-), U7.4 (V-), U$4.P2
AD9833_FS: U$1.P$10 (G26), U$2.FSYNC
AD9833_SCL: U$1.P$12 (G33), U$2.SCL
AD9833_SDA: U$1.P$13 (G32), U$2.SDA
AM_AUDIO_OUT: U4.5 (W), U$5.C0
AUDIO_OUTPUT: C16.-, U$6.P$1
DAC: U$1.P$11 (G25), VR3.3 (CW)
EN_A: U$1.P$15 (G34), X3.2
EN_B: U$1.P$14 (G35), X3.3
FM_AUDIO_OUT: U5.2 (STO), U$5.C1
GEN_FREQ: C1.+, U$2.OUT
GND: C4.-, C5.-, C6.-, C7.+, C8.-, C11.-, IC1.1 (GND), R4.1, R8.1, R15.1 (A), U1.3 (NON-INV_INPUT), U2.2 (GND), U2.5 (ADDR), U3.3 (NON-INV_INPUT), U4.2 (Y2), U4.4 (Z), U4.8 (X2), U5.12 (GND), U6.3 (NON-INV_INPUT), U7.3 (NON-INV_INPUT), U$1.P$6 (GND), U$1.P$20 (GND2), U$1.P$26 (GND3), U$2.AGND, U$2.DGND, U$3.P$1 (IN-), U$4.P1, U$5.EN, U$6.P$2, U$7.P$2, U$8.GND_1, U$8.GND_2, VR3.1 (CCW), X1.4, X2.3, X3.4, X4.2
MIXER_OUT: C16.+, R11.2, U7.6 (OUTPUT)
MOTOR: U$1.P$32 (G4), X4.1
MUX_OUTPUT: C15.+, U$5.SIG
unnamed: R2.2, U1.2 (INV_INPUT), VR1.1 (CCW)
unnamed: C2.-, R2.1
unnamed: R1.1, U5.3 (MO)
unnamed: R14.2, U3.2 (INV_INPUT), VR2.1 (CCW)
unnamed: C1.-, R14.1
unnamed: R1.2, R3.1, R4.2
unnamed: C3.1, U5.5 (TC1)
unnamed: C3.2, U5.6 (TC2)
unnamed: U5.7 (TR1), VR3.2 (WIPER)
unnamed: R5.2, U5.13 (WAVEA1)
unnamed: R5.1, U5.14 (WAVEA2)
unnamed: R6.1, U5.11 (SYNCO)
unnamed: C4.+, U5.10 (BIAS)
unnamed: C10.2, IC1.5 (INPUT)
unnamed: C9.+, IC1.2 (VCA_IN)
unnamed: C9.-, IC1.4 (BUFOUT)
unnamed: C11.+, IC1.6 (AVGCAP)
unnamed: IC1.8 (CMPRS), VR5.3 (CW)
unnamed: IC1.7 (GATE), VR4.3 (CW)
unnamed: C12.+, IC1.9 (OUTPUT)
unnamed: R9.2, U6.2 (INV_INPUT), VR6.1 (CCW)
unnamed: C14.-, R9.1
unnamed: R10.2, R11.1, R12.2, U7.2 (INV_INPUT)
unnamed: C13.-, R10.1
unnamed: C15.-, R12.1
PREAMP_IN: C10.1, U$7.P$1
PREAMP_OUT: C2.+, C12.-, R8.2
RX1: U$1.P$31 (G16), U$8.TX
S0: U$1.P$16 (SN), U$5.S0
S1: U$1.P$17 (SP), U$5.S1
S2: U$1.P$27 (G19), U$5.S2
S3: U$1.P$28 (G18), U$5.S3
SCL: U2.3 (SCL), U$1.P$22 (G22), X1.2
SDA: U2.4 (SDA), U$1.P$25 (G21), X1.3
SG1_IN: U3.6 (OUTPUT), U4.1 (Y1), U$5.C2, VR2.2 (WIPER)
SG3_IN: U1.6 (OUTPUT), U4.7 (X1), U$5.C3, VR1.2 (WIPER)
SW_PREAMP: IC1.3 (SHTDN), R7.2
TX1: U$1.P$30 (G17), U$8.RX
V_ESP32: U$1.P$1 (5V), U$3.P$3 (OUT+)
V_POT: R15.2 (S), U2.7 (A0)
WAV_FIXED: C13.+, U6.6 (OUTPUT), VR6.2 (WIPER)
WAV_OUT: C14.+, U$8.SPK1 (SPK_1)
WS2812: U$1.P$34 (G2), X2.2

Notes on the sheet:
ESP -WROOM 32 MODULE
AD9833 FREQ GENERATOR
ADS1115 ADC
CONNECTORS
SIGNAL 1 AMPLIFIER
VOLTAGE DIVIDER
SIGNAL 2 AMPLIFIER
AD633 ANALOG MULTIPLIER
LM2596 DC-DC REGULATOR
RGB LED CONNECTOR
I2C PORT
ENCODER
VIBRATOR
VCO FM MODULATOR
MUTIPLEXER
SSM2167 PREAMP - COMPRESSOR
WAV AUDIO PLAYER
OUT AUDIO MIXER
INSERTE NOMBRE PCB VERSION 1.3
MICHEL ROZAS <mvrozas@uc.cl>
Release date: 23-01-2024

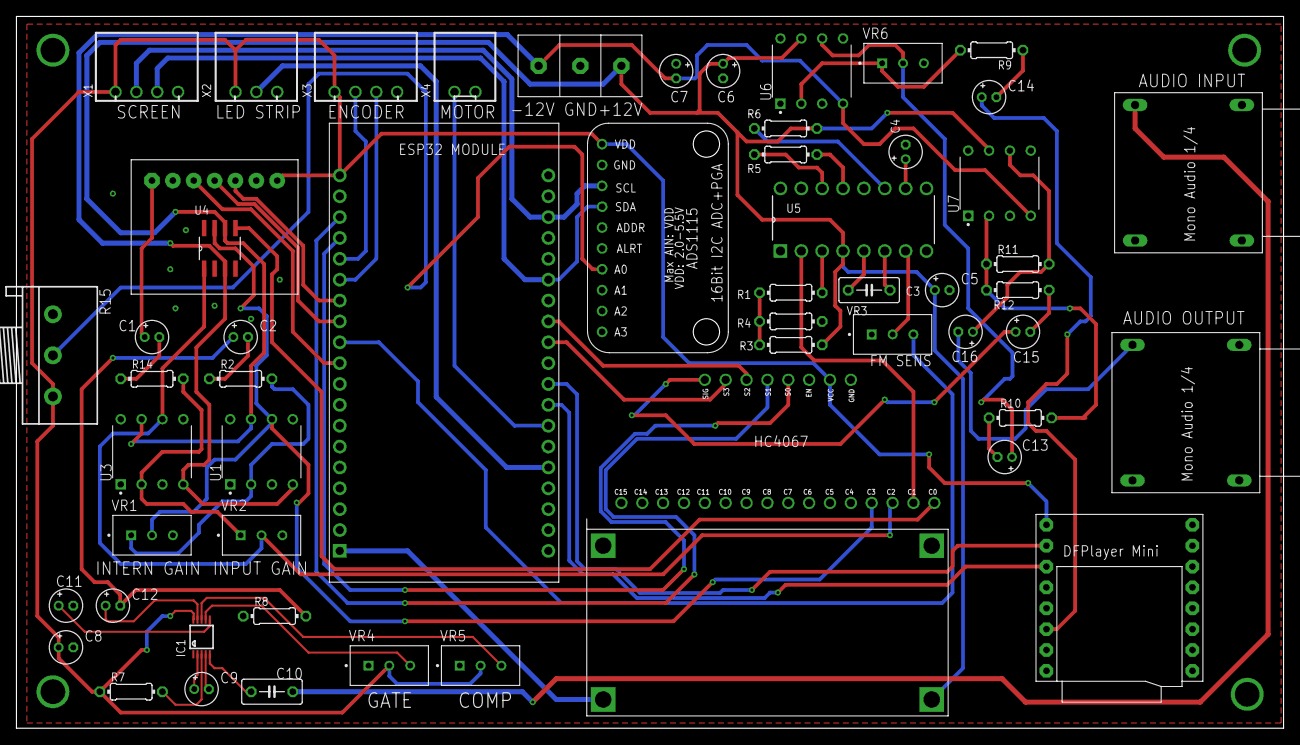
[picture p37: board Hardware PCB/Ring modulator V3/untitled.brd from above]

Board: 2 copper layers, 154.3 x 86.7 mm, 56 parts (0 on the bottom side), 60 nets.

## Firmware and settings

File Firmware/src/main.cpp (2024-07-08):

/* 
Ring modulator firmware made by Michel Rozas <mvrozas@uc.cl> for ESP32 WROOM 32D microcontroller

Open source libraries used in this project:

- Library for daumemo.com for AD9833 by Analog Devices
- IIR Filter Library - Copyright (C) 2016  Martin Vincent Bloedorn
- ESP32Encoder - https://registry.platformio.org/libraries/madhephaestus/ESP32Encoder
- SmartLEDS - https://registry.platformio.org/libraries/roboticsbrno/SmartLeds
- SSD1306 OLED screen - https://registry.platformio.org/libraries/adafruit/Adafruit%20SSD1306
- ADS1115 ADC - https://registry.platformio.org/libraries/adafruit/Adafruit%20ADS1X15
*/

#include <Arduino.h>
#include <WiFi.h>
#include <SPI.h>
#include <Wire.h>
#include <filters.h>
#include <Adafruit_ADS1X15.h> 
#include <Adafruit_GFX.h>
#include <Adafruit_SSD1306.h>
#include <SmartLeds.h>
#include <ESP32Encoder.h>  
#include "DacESP32.h"
#include "ad9833.h"
#include "DFRobotDFPlayerMini.h"


#define ENCODER1_A 23        // CLK ENCODER 1
#define ENCODER1_B 27        // DT ENCODER  1

#define ENCODER2_A 35        // CLK ENCODER 2
#define ENCODER2_B 34        // DT ENCODER  2

#define SCREEN_WIDTH 128     // OLED display width, in pixels
#define SCREEN_HEIGHT 64     // OLED display height, in pixels

#define I2C_SDA1 21          // I2C Screen and ADC pins
#define I2C_SCL1 22          // I2C Screen and ADC pins

#define MUX_S0  5            // MUX pin s0
#define MUX_S1 13            // MUX pin s1
#define MUX_S2 19            // MUX pin s2
#define MUX_S3 18            // MUX pin s3

#define DFPLAYER_TX 16       // Wav player Tx pin
#define DFPLAYER_RX 17       // Wav player Rx pin

//Instance the DFrobot player mini 
DFRobotDFPlayerMini DFPlayer;

const int LED_COUNT = 16;     // Number of LEDs
const int DATA_PIN = 2;       // LED strip pin
const int CHANNEL = 0;        // LED strip channel

//Tasks for RTOS
TaskHandle_t Task1;
TaskHandle_t Task2;

//TwoWire begin
TwoWire I2C1 = TwoWire(0);
TwoWire I2C2 = TwoWire(1);

//Declaration for an SSD1306 display connected to I2C (SDA, SCL pins)
Adafruit_SSD1306 display(SCREEN_WIDTH, SCREEN_HEIGHT, &I2C1, 4);

//ADS1115 ADC init
Adafruit_ADS1115 ads;        

//ESP32 DAC 
DacESP32 dac1(DAC_CHANNEL_1);

  
// SmartLed -> RMT driver (WS2812/WS2812B/SK6812/WS2813)
SmartLed leds(LED_WS2812B, LED_COUNT, DATA_PIN, CHANNEL, DoubleBuffer);

//Instance for the encoders
ESP32Encoder encoder1;
ESP32Encoder encoder2;


//Global Variables
float out = 0;           // Frequency selected after mapping
int disc_in = 0;         // potentiometer quantization to 8 bits
uint8_t led_state = 0;   // Selected LED set
uint8_t number = 0;      // Number reated to Mantra configurations
uint8_t mode = 0 ;       // Mode of mapping
uint8_t mux_output = 0;  // Mux output value 
uint8_t screen_flag = 0; // Flag to detect if a mode change occurred
uint8_t input_adc = 0;   // 0: Potentiometer   1: Slider
long newPosition = 0;    // Flag for encoder changes 
float input_freq = 0;    // Freq (is routed to Modulator)
uint8_t color_r = 0;     // Set the led colors
uint8_t color_g = 0;     // Set the led colors
uint8_t color_b = 50;    // Set the led colors
String note;             // string to store the value of each note in American key

// Frecuencias en Hz (multiplicadas por 2)
float freq1  = 184.0;    // Gb2    12 
float freq2  = 220.0;    // A2     1
float freq3  = 233.0;    // Bb2    11
float freq4  = 246.94;   // B2     2
float freq5  = 261.6;    // C3     10
float freq6  = 277.18;   // Db3    9
float freq7  = 293.66;   // D3     6
float freq8  = 311.12;   // Eb3    8
float freq9  = 329.62;   // E3     4
float freq10 = 349.22;   // F3     5
float freq11 = 391.96;   // G3     7
float freq12 = 415.3;    // G#3    3
float freq13 = 369.0;    // F#3    13 ???     
float freq14 = 440.0;    // A3     14 ???
float freq15 = 880.0;    // A4     15 ???
float freq16 = 3520.0;   // A6     16 ???

// Frecuencias en Hz (multiplicadas por 2)
float m3freq1  = 116.54;  // Bb1   3  
float m3freq2  = 123.48;  // B1    7
float m3freq3  = 138.6;   // C#2   5
float m3freq4  = 146.84;  // D2    4
float m3freq5  = 155.56;  // Eb2   8
float m3freq6  = 164.82;  // E2    6
float m3freq7  = 174.62;  // F2    9
float m3freq8  = 185.0;   // Gb2   10
float m3freq9  = 196.0;   // G2    2
float m3freq10 = 207.66;  // Ab2   11
float m3freq11 = 220.0;   // A2    1
float m3freq12 = 261.62;  // C3    12
float m3freq13 = 329.0;   // E3    13 ???
float m3freq14 = 415.0;   // G#3   14 ???
float m3freq15 = 880.0;   // A4    15 ???
float m3freq16 = 1760.0;  // A5    16 ???

// Select values between 0-255 to define the pot trheshols
uint8_t m1th1  = 25 ;
uint8_t m1th2  = 50 ;
uint8_t m1th3  = 75 ;
uint8_t m1th4  = 90 ;
uint8_t m1th5  = 105 ;
uint8_t m1th6  = 120 ;
uint8_t m1th7  = 145 ;
uint8_t m1th8  = 160 ;
uint8_t m1th9  = 175 ;
uint8_t m1th10 = 190 ;
uint8_t m1th11 = 210 ;
uint8_t m1th12 = 230 ;

// Select values between 0-255 to define the pot thresholds
uint8_t m2th1  = 9 ;    // 0-9    : Constant in Gb2
uint8_t m2th2  = 18 ;   // 9-18   : Linear mapping between Gb2 / A2
uint8_t m2th3  = 27 ;   // 18-27  : Constant in A2
uint8_t m2th4  = 36 ;   // 27-36  : Linear mapping between A2 / Bb2
uint8_t m2th5  = 45 ;   // 36-45  : Constant in Bb2
uint8_t m2th6  = 54 ;   // 45-54  : Linear mapping between Bb2 / B2
uint8_t m2th7  = 63 ;   // 54-63  : Constant in B2
uint8_t m2th8  = 72 ;   // 63-72  : Linear mapping between B2 / C3
uint8_t m2th9  = 81 ;   // 72-81  : Constant in C3
uint8_t m2th10 = 90 ;   // 81-90  : Linear mapping between C3 / Db3
uint8_t m2th11 = 99 ;   // 90-99  : Constant in Db3
uint8_t m2th12 = 108 ;  // 99-108 : Linear mapping between Db3 / D3
uint8_t m2th13 = 117 ;  // 108-117: Constant in D3
uint8_t m2th14 = 126 ;  // 117-126: Linear mapping between D3 / Eb3
uint8_t m2th15 = 135 ;  // 126-135: Constant in Eb3
uint8_t m2th16 = 144 ;  // 135-144: Linear mapping between Eb3 / E3
uint8_t m2th17 = 153 ;  // 144-153: Constant in E3
uint8_t m2th18 = 162 ;  // 153-162: Linear mapping between E3 / F3
uint8_t m2th19 = 171 ;  // 162-171: Constant in F3
uint8_t m2th20 = 180 ;  // 171-180: Linear mapping between F3 / G3
uint8_t m2th21 = 189 ;  // 180-189: Constant in G3
uint8_t m2th22 = 198 ;  // 189-198: Linear mapping between G3 / G#3
uint8_t m2th23 = 207 ;  // 198-207: Constant in G#3
uint8_t m2th24 = 216 ;  // 207-216: Constant in F#3
uint8_t m2th25 = 225 ;  // 216-225: Constant in A3
uint8_t m2th26 = 234 ;  // 225-234: Constant in A4
uint8_t m2th27 = 255 ;  // 234-255: Constant in A6

                     

// Select values between 0-255 to define the pot thresholds
uint8_t m3th1  = 9 ;    // 0-9     : Constant in Bb1
uint8_t m3th2  = 18 ;   // 9-18    : Linear mapping between Bb1 / B1
uint8_t m3th3  = 27 ;   // 18-27   : Constant in B1
uint8_t m3th4  = 36 ;   // 27-36   : Linear mapping between B1 / C#2
uint8_t m3th5  = 45 ;   // 36-45   : Constant in C#2
uint8_t m3th6  = 54 ;   // 45-54   : Linear mapping between C#2 / D2
uint8_t m3th7  = 63 ;   // 54-63   : Constant in D2
uint8_t m3th8  = 72 ;   // 63-72   : Linear mapping between D2 / Eb2
uint8_t m3th9  = 81 ;   // 72-81   : Constant in Eb2
uint8_t m3th10 = 90 ;   // 81-90   : Linear mapping between Eb2 / E2
uint8_t m3th11 = 99 ;   // 90-99   : Constant in E2
uint8_t m3th12 = 108 ;  // 99-108  : Linear mapping between E2 / F2
uint8_t m3th13 = 117 ;  // 108-117 : Constant in F2
uint8_t m3th14 = 126 ;  // 117-126 : Linear mapping between F2 / Gb2
uint8_t m3th15 = 135 ;  // 126-135 : Constant in Gb2
uint8_t m3th16 = 144 ;  // 135-144 : Linear mapping between Gb2 / G2
uint8_t m3th17 = 153 ;  // 144-153 : Constant in G2
uint8_t m3th18 = 162 ;  // 153-162 : Linear mapping between G2 / Ab2
uint8_t m3th19 = 171 ;  // 162-171 : Constant in Ab2
uint8_t m3th20 = 180 ;  // 171-180 : Linear mapping between Ab2 / A2
uint8_t m3th21 = 189 ;  // 180-189 : Constant in A2
uint8_t m3th22 = 198 ;  // 189-198 : Linear mapping between A2 / C3
uint8_t m3th23 = 207 ;  // 198-207 : Constant in C3
uint8_t m3th24 = 216 ;  // 207-216 : Constant in E3
uint8_t m3th25 = 225 ;  // 216-225 : Constant in G#3
uint8_t m3th26 = 234 ;  // 225-234 : Constant in A4
uint8_t m3th27 = 255 ;  // 234-255 : Constant in A5


void off_leds(){
  for(int i=0;i<16;i++){
    leds[i] = Rgb { 0, 0, 0 };
  }
}

void show_leds(){
  if(mode == 0)      { color_b=100;color_g=0;color_r=0; }
  else if (mode == 1){ color_b=0;color_g=100;color_r=0; }
  else if (mode == 2){ color_b=0;color_g=0;color_r=100; }
  else if (mode == 3){ color_b=100;color_g=100;color_r=0; }
  else if (mode == 4){ color_b=100;color_g=0;color_r=100; }
  else if (mode == 5){ color_b=120;color_g=70;color_r=0; }
  else               { color_b=100;color_g=100;color_r=100;}
  off_leds();
  leds[15 - led_state] = Rgb { color_r, color_g, color_b};
  if(led_state == 0){
    off_leds();
  }
  leds.show();
}

float map_pot(int in){
  
  int threshold = 17000;
  disc_in = map(in,0,threshold,0,255);

  //Modo 0: Saltos discretos entre frecuencias
  if ( mode == 0){
    if(disc_in>=0    && disc_in <m1th1) {out=freq1; led_state = 2;}
    else if(disc_in>=m1th1  && disc_in <m1th2) {out=freq2; led_state = 3;}
    else if(disc_in>=m1th2  && disc_in <m1th3) {out=freq3; led_state = 4;}
    else if(disc_in>=m1th3  && disc_in <m1th4) {out=freq4; led_state = 5;}
    else if(disc_in>=m1th4  && disc_in <m1th5) {out=freq5; led_state = 6;}
    else if(disc_in>=m1th5  && disc_in <m1th6) {out=freq6; led_state = 7;}
    else if(disc_in>=m1th6  && disc_in <m1th7) {out=freq7; led_state = 8;}
    else if(disc_in>=m1th7  && disc_in <m1th8) {out=freq8; led_state = 9;}
    else if(disc_in>=m1th8  && disc_in <m1th9) {out=freq9; led_state = 10;}
    else if(disc_in>=m1th9  && disc_in <m1th10){out=freq10;led_state = 11;}
    else if(disc_in>=m1th10 && disc_in <m1th11){out=freq11;led_state = 12;}
    else if(disc_in>=m1th11 && disc_in <m1th12){out=freq12;led_state = 13;}
    else if(disc_in>=m1th12)                 {out=freq13;led_state = 14;}
    else { out = 0;}
  }

  //Mode 1: Piano 1 (Normal mode) Gradual jumps between frequencies (Mapping with linear interpolation)
  else if (mode == 1){
    if(disc_in>=0    && disc_in <m2th1) {out=freq1; led_state = 2; number = 12;note = "Gb2";}
    else if(disc_in>=m2th1  && disc_in <m2th2) {out=map(disc_in,m2th1,m2th2,freq1,freq2); led_state = 0;number = 0;}
    else if(disc_in>=m2th2  && disc_in <m2th3) {out=freq2; led_state = 2; number = 1;note = "A2";}
    else if(disc_in>=m2th3  && disc_in <m2th4) {out=map(disc_in,m2th3,m2th4,freq2,freq3); led_state = 0;number = 0;}
    else if(disc_in>=m2th4  && disc_in <m2th5) {out=freq3; led_state = 3; number = 11;note = "Bb2";}
    else if(disc_in>=m2th5  && disc_in <m2th6) {out=map(disc_in,m2th5,m2th6,freq3,freq4); led_state = 0;number = 0;}
    else if(disc_in>=m2th6  && disc_in <m2th7) {out=freq4; led_state = 4; number = 2;note = "B2";}
    else if(disc_in>=m2th7  && disc_in <m2th8) {out=map(disc_in,m2th7,m2th8,freq4,freq5); led_state = 0;number = 0;}
    else if(disc_in>=m2th8  && disc_in <m2th9) {out=freq5; led_state = 5; number = 10;note = "C3";}
    else if(disc_in>=m2th9  && disc_in <m2th10){out=map(disc_in,m2th9,m2th10,freq5,freq6); led_state = 0;number = 0;}
    else if(disc_in>=m2th10 && disc_in <m2th11){out=freq6; led_state = 6; number = 9;note = "Db3";}
    else if(disc_in>=m2th11 && disc_in <m2th12){out=map(disc_in,m2th11,m2th12,freq6,freq7); led_state = 0;number = 0;}
    else if(disc_in>=m2th12 && disc_in <m2th13){out=freq7; led_state = 7; number = 6;note = "D3";}
    else if(disc_in>=m2th13 && disc_in <m2th14){out=map(disc_in,m2th13,m2th14,freq7,freq8); led_state = 0;number = 0;}
    else if(disc_in>=m2th14 && disc_in <m2th15){out=freq8; led_state = 8; number = 8;note = "Eb3";}
    else if(disc_in>=m2th15 && disc_in <m2th16){out=map(disc_in,m2th15,m2th16,freq8,freq9); led_state = 0;number = 0;}
    else if(disc_in>=m2th16 && disc_in <m2th17){out=freq9; led_state = 9; number = 4;note = "E3";}
    else if(disc_in>=m2th17 && disc_in <m2th18){out=map(disc_in,m2th17,m2th18,freq9,freq10); led_state = 0;number = 0;}
    else if(disc_in>=m2th18 && disc_in <m2th19){out=freq10; led_state = 10; number = 5;note = "F3";}
    else if(disc_in>=m2th19 && disc_in <m2th20){out=map(disc_in,m2th19,m2th20,freq10,freq11); led_state = 0;number = 0;}
    else if(disc_in>=m2th20 && disc_in <m2th21){out=freq11; led_state = 11; number = 7;note = "G3";}
    else if(disc_in>=m2th21 && disc_in <m2th22){out=map(disc_in,m2th21,m2th22,freq11,freq12); led_state = 0;number = 0;}
    else if(disc_in>=m2th22 && disc_in <m2th23){out=freq12; led_state = 12;number = 3;note = "G#3";}
    else if(disc_in>=m2th23 && disc_in <m2th24){out=freq13; led_state = 0;number = 13;note = "F#3";}
    else if(disc_in>=m2th24 && disc_in <m2th25){out=freq14; led_state = 0;number = 14;note = "A3";}
    else if(disc_in>=m2th25 && disc_in <m2th26){out=freq15; led_state = 0;number = 15;note = "A4";}
    else if(disc_in>=m2th26 && disc_in <m2th27){out=freq16; led_state = 0;number = 16;note = "A6";}

    else { out = 0;}
  }
  
  //Mode 2: Piano 2 (Normal mode) Gradual jumps between frequencies (Mapping with linear interpolation)
  else if (mode == 2){
    if(disc_in>=0    && disc_in <m3th1) {out=m3freq1; led_state = 2; number = 3;note = "Bb1";}
    else if(disc_in>=m3th1  && disc_in <m3th2) {out=map(disc_in,m3th1,m3th2,m3freq1,m3freq2); led_state = 0;number = 0;}
    else if(disc_in>=m3th2  && disc_in <m3th3) {out=m3freq2; led_state = 2; number = 7;note = "B1";}
    else if(disc_in>=m3th3  && disc_in <m3th4) {out=map(disc_in,m3th3,m3th4,m3freq2,m3freq3); led_state = 0;number = 0;}
    else if(disc_in>=m3th4  && disc_in <m3th5) {out=m3freq3; led_state = 3; number = 5;note = "C#2";}
    else if(disc_in>=m3th5  && disc_in <m3th6) {out=map(disc_in,m3th5,m3th6,m3freq3,m3freq4); led_state = 0;number = 0;}
    else if(disc_in>=m3th6  && disc_in <m3th7) {out=m3freq4; led_state = 4; number = 4;note = "D2";}
    else if(disc_in>=m3th7  && disc_in <m3th8) {out=map(disc_in,m3th7,m3th8,m3freq4,m3freq5); led_state = 0;number = 0;}
    else if(disc_in>=m3th8  && disc_in <m3th9) {out=m3freq5; led_state = 5; number = 8;note = "Eb2";}
    else if(disc_in>=m3th9  && disc_in <m3th10){out=map(disc_in,m3th9,m3th10,m3freq5,m3freq6); led_state = 0;number = 0;}
    else if(disc_in>=m3th10 && disc_in <m3th11){out=m3freq6; led_state = 6; number = 6;note = "E2";}
    else if(disc_in>=m3th11 && disc_in <m3th12){out=map(disc_in,m3th11,m3th12,m3freq6,m3freq7); led_state = 0;number = 0;}
    else if(disc_in>=m3th12 && disc_in <m3th13){out=m3freq7; led_state = 7; number = 9;note = "F2";}
    else if(disc_in>=m3th13 && disc_in <m3th14){out=map(disc_in,m3th13,m3th14,m3freq7,m3freq8); led_state = 0;number = 0;}
    else if(disc_in>=m3th14 && disc_in <m3th15){out=m3freq8; led_state = 8; number = 10;note = "Gb2";}
    else if(disc_in>=m3th15 && disc_in <m3th16){out=map(disc_in,m3th15,m3th16,m3freq8,m3freq9); led_state = 0;number = 0;}
    else if(disc_in>=m3th16 && disc_in <m3th17){out=m3freq9; led_state = 9; number = 2;note = "G2";}
    else if(disc_in>=m3th17 && disc_in <m3th18){out=map(disc_in,m3th17,m3th18,m3freq9,m3freq10); led_state = 0;number = 0;}
    else if(disc_in>=m3th18 && disc_in <m3th19){out=m3freq10; led_state = 10;number = 11;note = "Ab2";}
    else if(disc_in>=m3th19 && disc_in <m3th20){out=map(disc_in,m3th19,m3th20,m3freq10,m3freq11); led_state = 0;number = 0;}
    else if(disc_in>=m3th20 && disc_in <m3th21){out=m3freq11; led_state = 11; number = 1;note = "A2";}
    else if(disc_in>=m3th21 && disc_in <m3th22){out=map(disc_in,m3th21,m3th22,m3freq11,m3freq12); led_state = 0;number = 0;}
    else if(disc_in>=m3th22 && disc_in <m3th23){out=m3freq12; led_state = 12; number = 12;note = "C3";}
    else if(disc_in>=m3th23 && disc_in <m3th24){out=m3freq13; led_state = 0; number = 13;note = "E3";}
    else if(disc_in>=m3th24 && disc_in <m3th25){out=m3freq14; led_state = 0; number = 14;note = "G#3";}
    else if(disc_in>=m3th25 && disc_in <m3th26){out=m3freq15; led_state = 0; number = 15;note = "A4";}
    else if(disc_in>=m3th26 && disc_in <m3th27){out=m3freq16; led_state = 0; number = 16;note = "A5";}
    else { out = 0;}
  }

  //Modo 3: recorrido continuo entre 1 Hz y 5 kHz 
  else if (mode == 3){
    out = map(in,0,threshold,0,5000);
    led_state = map(in,0,threshold,2,15);
  }

  //Modo 4: recorrido continuo entre 1 Hz y 1 kHz 
  else if (mode == 4){
    out = map(in,0,threshold,0,1000);
    led_state = map(in,0,threshold,2,15);
  }

  //Modo 5: recorrido continuo entre 1 Hz y 500 Hz 
  else if (mode == 5){
    out = map(in,0,threshold,0,500);
    led_state = map(in,0,threshold,2,15);
  }

  //En cualquier otro caso, se apaga el oscilador local 
  else{
    out = 0;
    led_state = 0;
  }
  return out;
}

void update_display(){
  
  if ((mode == 1 || mode == 2)){ 
    display.clearDisplay();
    display.setTextSize(1);
    display.setCursor(5,1);
    if(mode == 1){
      display.print("MODE:Mantra-Piano I");
    }
    else{
      display.print("MODE:Mantra-Piano II");
    }
    display.setTextSize(2);
    display.setCursor(15, 20);
    display.print("NOTE");
    display.setCursor(85, 20);
    display.print("Nro");
    if(number == 0){
      display.setCursor(15, 45);
    }
    else{
      display.setCursor(22, 45);
      display.print(note);
      display.setCursor(95, 45);
      display.print(number);
    }
    display.display(); 
    screen_flag = 1;
  }

  else if (mode == 3 || mode == 4 || mode == 5){
    if(screen_flag == 1){
      display.clearDisplay();
      display.setCursor(40, 10);
      display.print("MODE");
      display.setCursor(5, 40);
      display.print("CONTINUOUS");
      display.display();
      screen_flag = 0; //Show only once
    }
  }

  else{
    display.clearDisplay();
    display.setTextSize(1);
    display.setCursor(5,1);
    display.print("MODE: Test");
    display.setTextSize(2);
    display.setCursor(5, 20);
    display.print("Frecuencia");
    display.setCursor(5, 45);
    display.print(input_freq);
    display.setCursor(100, 40);
    display.print("Hz");
    display.display(); 
    screen_flag = 1;
  }
}

void change_mux(int val) {
    switch(val) {
        case 0:  // AM
            digitalWrite(MUX_S0, LOW);
            digitalWrite(MUX_S1, LOW);
            digitalWrite(MUX_S2, LOW);
            digitalWrite(MUX_S3, LOW);
            break;
        case 1: // FM
            digitalWrite(MUX_S0, HIGH);
            digitalWrite(MUX_S1, LOW);
            digitalWrite(MUX_S2, LOW);
            digitalWrite(MUX_S3, LOW);
            break;
        case 2:  // BYPASS
            digitalWrite(MUX_S0, LOW);
            digitalWrite(MUX_S1, HIGH);
            digitalWrite(MUX_S2, LOW);
            digitalWrite(MUX_S3, LOW);
            break;
        case 3:  // LOCAL SG
            digitalWrite(MUX_S0, HIGH);
            digitalWrite(MUX_S1, HIGH);
            digitalWrite(MUX_S2, LOW);
            digitalWrite(MUX_S3, LOW);
            break;
        default:
            // Opcional: manejar valores fuera del rango esperado
            break;
    }
}
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
void loop(){
  
}
